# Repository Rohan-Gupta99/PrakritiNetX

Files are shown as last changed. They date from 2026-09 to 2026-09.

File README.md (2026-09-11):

# PrakritiNetX

> **An Autonomous, AI-Accelerated Environmental Early Warning & Hydro-Meteorological Intelligence Network for Flash Floods, Forest Fires, and Landslide Precursors in Mountain River Basins.**







---

## 1. Project Information

| Field | Details |
|---|---|
| **Project Title** | PrakritiNetX – AI-Accelerated Environmental Early Warning Network |
| **PS ID** | SIH2026-26178 |
| **PS Title** | AI-based environmental early warning and hydro-meteorological intelligence system for flash floods, forest fires, and landslide precursors in mountain river basins |
| **Category** | Hardware |
| **Theme** | Disaster Management |

### Team Members

| Name | Roll Number |
|---|---|
| Anishka Gupta | 2024UEC2562 |
| Rohan Gupta | 2024UEC2565 |
| Vansh Kumar | 2024UEC2519 |
| Nishant Kumar | 2024UEC2516 |
| Vivek Kumar | 2024UEC2509 |
| Animesh | 2024UEE4152 |

---

## 2. Problem Statement

Traditional environmental monitoring in India's Himalayan river basins relies on single-point **threshold-based detectors** — sensors that sound an alarm only after a river crosses a fixed water level or smoke reaches a localized probe. In steep mountain watersheds, these fixed thresholds fail physically:

- A water level routine on a wide lowland river represents a devastating flash flood on a narrow mountain gorge.
- Hardcoded threshold logic produces perpetual false alarms during seasonal snowmelt or misses sudden cloudburst pulses entirely.
- By the time an in-stream probe detects a 3-meter surge, the flood wave is already destroying infrastructure and lives downstream.
- Manual identification of forest fires and landslide precursors depends on delayed satellite imagery or chance human reporting.

There is no integrated, autonomous system that can predict flash floods, forest fires, and landslide events **before** they happen, with hours of actionable lead time, while operating off-grid in remote mountain terrain.

---

## 3. Proposed Solution

**PrakritiNetX shifts disaster management from reactive detection to predictive intelligence.** It is a distributed network of ruggedized, solar-powered edge computing nodes deployed across mountain river basins. Each node captures leading physical precursors rather than late-stage symptoms:

1. **Multi-Station Kinematic Forecasting**: Distributed edge nodes capture rate of suspended sediment turbidity change (dτ/dt), river surface texture agitation via on-device CNN vision, rainfall accumulation, and micro-seismic slope creep — all upstream precursors, not downstream consequences.
2. **Per-Site Learned Normal (30-Day μ, σ)**: Each node's baseline adapts to seasonal monsoon transitions. Anomalies are quantified via standard-deviation departures (Z ≥ 3.0σ) relative to that specific site's own historical normal — eliminating false alarms.
3. **Cross-Node Kinematic Wave Correlation**: When an upstream station flags an anomaly, the central predictive engine computes downstream arrival times (Δt = d/v) using precise field GNSS coordinates, delivering **hours of lead time** to civil defense authorities.
4. **Transparent, Auditable Escalation**: All alerting decisions follow deterministic, explainable rules matching Central Water Commission (CWC) operational standards — no black-box failures during life-safety events.

### Command Center Dashboard

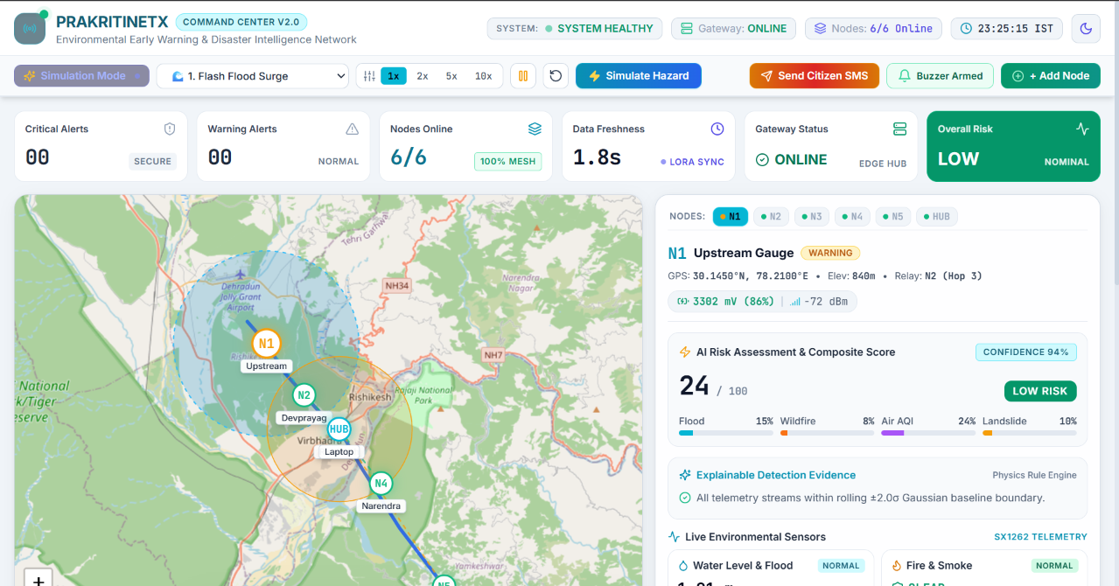
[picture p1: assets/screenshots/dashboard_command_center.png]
Command Center Dashboard


```
                    UPSTREAM SENSING STATION                               DOWNSTREAM COMMUNITY
                 [Precursor Detected at t = 0]                           [Predicted Arrival at t + Δt]
                   +------------------------+                             +------------------------+
                   | Node #1: Alaknanda #4  |                             | Node #2: Devprayag #1  |
                   | (Precise GNSS Geotag)  |                             | (Precise GNSS Geotag)  |
                   +-----------+------------+                             +-----------+------------+
                               |                                                      ^
                      Rate-of-Change (dτ/dt)                                          |
                               |                                                      |
                               v                                                      |
                   +------------------------+    Kinematic Propagation Model          |
                   | Central Predictive Hub |=========================================+
                   | (Rolling 30-day μ, σ)  |       Δt = Distance / River Velocity
                   +-----------+------------+
                               |
                   [Deterministic Rule Escalation]
                               v
                   +------------------------+
                   | NDMA SACHET / SMS / CAP| ---> District Disaster Authorities (DDMA)
                   +------------------------+      & Downstream Riverine Populations
```

---

## 4. Key Features

- **Flash Flood Prediction** — Upstream kinematic wave analysis with cross-node arrival time forecasting
- **Forest Fire Detection** — Real-time MobileNet CNN smoke/fire binary classification on K210 KPU + IR flame wake trigger
- **Landslide Precursor Monitoring** — Micro-seismic tremor filtering (ADXL355 accelerometer) + dual-axis tilt (SCA100T) for slope deformation
- **WaterNet On-Device Vision** — Tiny water-segmentation CNN (90K params, 104 KB .kmodel) for river level, coverage, turbidity, and debris measurement
- **Real-Time Command Center Dashboard** — Vite + React frontend with Python/FastAPI backend for live node monitoring, hazard simulation, and alert management
- **Per-Site Adaptive Baselines** — 30-day rolling statistical normal per node eliminates false alarms during monsoon transitions
- **Sub-GHz LoRa Mesh Network** — 433 MHz peer-to-peer mesh with ridge repeaters for zero-cellular mountain deployments
- **FieldFlash Mobile Provisioner** — Native Android (Kotlin) app for USB-OTG firmware flashing, GNSS geotagging, and node registration in the field
- **Custom PCB Design** — KiCad-designed sensor board with LoRaWAN, camera/SD, and environmental sensor subsystems
- **3D Product Design** — FreeCAD-modeled solar-powered node pole housing (STL export for manufacturing)
- **Industrial Power-Gating** — Dual power domain design (ESP32 always-on radio + K210 power-gated vision) for 10–14+ days overcast autonomy
- **NDMA/CWC Compliant Alerting** — Deterministic escalation via SACHET/CAP/SMS to District Disaster Management Authorities

---

## 5. Technology Stack

| Layer | Technologies |
|---|---|
| **Edge Compute (Lite Tier)** | ESP32-S3 (Dual Xtensa LX7 @ 240 MHz), ULP Co-Processor, TinyML |
| **Edge Compute (Vision Tier)** | Kendryte K210 (Dual RISC-V @ 400 MHz), 0.5 TOPS KPU CNN Accelerator |
| **Sensors** | Davis 7852 Rain Gauge, ADXL355 Seismic Accelerometer, SCA100T Tilt Sensor, OV5647 5MP Camera, YG1006 IR Flame Trigger |
| **Communication** | 433 MHz Sub-GHz LoRa (SX1276/RFM95), Peer-to-Peer Mesh Topology |
| **Machine Learning** | TensorFlow/Keras, TFLite, nncase v0.2 (.kmodel v4 for K210 KPU) |
| **Dashboard Frontend** | React, TypeScript, Vite, Tailwind CSS |
| **Dashboard Backend** | Python, FastAPI, SQLite, Physics Simulation Engine |
| **Mobile App** | Android Native (Kotlin), USB-OTG Serial, Room DB, WorkManager, Retrofit |
| **Backend/Cloud** | AWS API Gateway + Lambda + DynamoDB + S3 (or local Raspberry Pi gateway) |
| **PCB Design** | KiCad (Schematics, PCB Layout) |
| **3D Design** | FreeCAD (Node Pole Housing, STL Export) |
| **Power System** | 12V LiFePO4 (15–20 Ah) + MPPT Solar Controller (10–20W Monocrystalline, IP65) |
| **Compliance** | NDMA CAP, SACHET, CWC Standards |

---

## 6. Architecture

### System-Level Architecture

```
┌──────────────────────────────────────────────────────────────────────────┐
│                     FIELD DEPLOYMENT LAYER                              │
│                                                                        │
│   ┌─────────────┐   ┌─────────────┐   ┌─────────────┐                │
│   │ Lite Node #1│   │ Vision Node │   │ Lite Node #3│                │
│   │ (ESP32-S3)  │   │ (K210+ESP32)│   │ (ESP32-S3)  │                │
│   │ Hydrology & │   │ Fire & River│   │ Landslide   │                │
│   │ Landslide   │   │ Dynamics    │   │ Monitoring  │                │
│   └──────┬──────┘   └──────┬──────┘   └──────┬──────┘                │
│          │                 │                  │                        │
│          └────────── 433 MHz LoRa Mesh ───────┘                       │
│                            │                                          │
└────────────────────────────┼──────────────────────────────────────────┘
                             │
                    ┌────────▼────────┐
                    │ LoRa Gateway /  │
                    │ Ridge Repeater  │
                    └────────┬────────┘
                             │
              ┌──────────────▼──────────────┐
              │   CENTRAL INTELLIGENCE HUB  │
              │                             │
              │  • 30-day μ,σ per station   │
              │  • Kinematic wave Δt calc   │
              │  • Z-score anomaly engine   │
              │  • Cross-node correlation   │
              └──────────────┬──────────────┘
                             │
              ┌──────────────▼──────────────┐
              │     ALERT DISSEMINATION     │
              │                             │
              │  • NDMA SACHET Integration  │
              │  • CAP XML Alerts           │
              │  • SMS to DDMA / Public     │
              │  • Dashboard / Web UI       │
              └─────────────────────────────┘
```

### Hardware Node Architecture

| System Specification | Lite Tier (Hydrology & Landslide) | Vision Tier (Forest Fire & River Dynamics) |
|---|---|---|
| **Primary Compute** | ESP32-S3 (Dual Xtensa LX7 @ 240 MHz) | Kendryte K210 (Dual 64-bit RISC-V @ 400 MHz) |
| **Co-Processor** | Ultra-Low-Power (ULP) Core | ESP32 (MSM261S4030H0 module for Comms/Sleep) |
| **AI Acceleration** | Espressif Vector Instructions (TinyML) | 0.5 TOPS KPU (Dedicated CNN Hardware Accelerator) |
| **Sensor Subsystem** | Rain gauge, ADXL355 seismic accelerometer, dual-axis tilt, soil moisture | OV5647 5MP camera + telephoto M12 lens + YG1006 IR flame wake trigger |
| **Edge Workload** | Micro-tremor filtering, slope deformation, surface runoff | Real-time MobileNet CNN smoke/fire classification & optical water texture variance |
| **Radio Link** | 433 MHz Sub-GHz LoRa (SX1276/RFM95) | 433 MHz Sub-GHz LoRa via ESP32 |
| **Autonomy** | 14+ consecutive overcast days | 10+ consecutive overcast days |

### FieldFlash Mobile Provisioning Workflow

```
┌─────────────────────────┐     ┌─────────────────────────┐     ┌─────────────────────────┐
│   1. REPOSITORY CACHE   │ --> │   2. USB HOST BRIDGE    │ --> │    3. FLASH ENGINES     │
│ Cloud Manifest / SAF    │     │ CP2102, CH340, CDC-ACM  │     │ ESP32 ROM & K210 ISP    │
│ Cryptographic Signatures│     │ Hardware Auto-Reset     │     │ Adaptive Baud Fallback  │
└─────────────────────────┘     └─────────────────────────┘     └────────────┬────────────┘
                                                                             │
┌─────────────────────────┐     ┌─────────────────────────┐                  │
│   5. GEOTAG & REGISTER  │ <-- │   4. BOOT DIAGNOSTICS   │ <────────────────┘
│ Multi-Constellation GNSS│     │ Serial Telemetry Query  │ (Strict Pass / Fail
│ Local Room DB Auto-Sync │     │ Version & CRC Matching  │  Zero Bricked Devices)
└─────────────────────────┘     └─────────────────────────┘
```

### Technical Approach

The diagram below illustrates the complete end-to-end technical architecture — from the edge AI sensor nodes (Maixduino K210 + ESP32) through the LoRa mesh network, Raspberry Pi gateway hub, and cloud/local data pipeline, all the way to SMS/call civil defense alerting and mobile firmware provisioning.

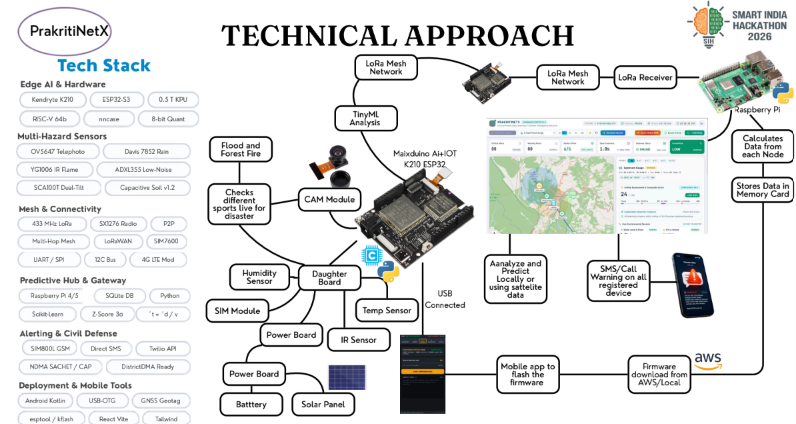
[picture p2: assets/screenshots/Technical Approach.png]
Technical Approach


---

## 7. Repository Structure

```
PrakritiNetX/
├── README.md                                    # Master project documentation
├── SUBMISSION_GUIDE.md                          # SIH 2026 submission checklist
├── LICENSE                                      # MIT Open Source License
├── requirements.txt                             # Root-level dependencies
├── .gitignore
│
├── Docs/
│   ├── Environmental Intelligence Network       # Complete technical reference (PDF)
│   │   — Complete Technical Reference.pdf
│   ├── SIH26178_PrakritiNetX_Disaster_          # SIH Presentation (PDF)
│   │   Management.pdf
│   └── architecture.md                          # Detailed system architecture document
│
├── Hardware/
│   ├── AI BOARD MAIN HOUSE/                     # Main board schematics & reference docs
│   │   ├── Advance Project 2.0.pdf
│   │   ├── Maixduino_2832(Schematic)_v1.5.pdf
│   │   └── maixduino_pins.png
│   ├── Sensor_board/                            # Custom PCB design (KiCad)
│   │   ├── Sensor_board.kicad_sch               # Main sensor board schematic
│   │   ├── Lorawan.kicad_sch                    # LoRaWAN sub-schematic
│   │   ├── camere_sd.kicad_sch                  # Camera & SD card sub-schematic
│   │   └── temp_humidity.kicad_sch              # Environmental sensor sub-schematic
│   ├── PRODUCT_DESIGN/
│   │   └── 3D_MODEL_NODE_POLE/                  # FreeCAD 3D model + STL export
│   └── Lib/                                     # KiCad component symbol library
│
├── Software/
│   ├── ML_Model/                                # WaterNet — On-device river vision CNN
│   │   ├── src/
│   │   │   ├── models/waternet.py               # KPU-legal CNN architecture (90K params)
│   │   │   ├── data/augment.py                  # Augmentation + synthetic water rise
│   │   │   ├── data/dataset.py                  # Auto-discovering image/mask loader
│   │   │   ├── train.py                         # Training (Dice + BCE loss, IoU metric)
│   │   │   └── export_kmodel.py                 # Keras → TFLite → ncc → .kmodel pipeline
│   │   ├── tools/                               # nncase v0.2 compiler & utilities
│   │   ├── firmware_ref/maixpy_node.py          # On-board K210 firmware
│   │   ├── datasets/                            # Training data directory
│   │   └── requirements.txt
│   │
│   ├── Main_Dashboard/                          # Real-Time Command Center Dashboard
│   │   ├── frontend/                            # React + TypeScript + Vite + Tailwind CSS
│   │   │   ├── src/                             # Dashboard UI components & pages
│   │   │   ├── package.json
│   │   │   └── vite.config.ts
│   │   └── backend/                             # Python FastAPI + SQLite
│   │       ├── main.py                          # API server & WebSocket endpoints
│   │       ├── physics_engine.py                # Kinematic wave & hazard simulation
│   │       ├── simulator.py                     # Multi-hazard scenario simulator
│   │       ├── database.py                      # SQLite data layer
│   │       ├── models.py                        # Pydantic data models
│   │       ├── packet_codec.py                  # LoRa binary packet encoder/decoder
│   │       └── requirements.txt
│   │
│   └── Mobile Firmware Flasher Application/     # FieldFlash — Android Provisioner App
│       ├── app/
│       │   └── src/main/java/org/prakritinetx/fieldflash/
│       │       ├── core/                        # State wrappers, constants, result models
│       │       ├── data/                        # Room SQLite DB, Retrofit REST, WorkManager
│       │       ├── engine/                      # Native ESP32 ROM & K210 ISP flash engines
│       │       ├── location/                    # GNSS location provider & board NVS writer
│       │       └── ui/                          # MVVM ViewModel, Wizard Fragments, Terminal
│       ├── mock_backend/                        # Local base-station gateway & integration tests
│       ├── preview_ui.html                      # Full-feature PC browser UI simulator
│       ├── build.gradle.kts
│       └── README.md                            # Detailed FieldFlash documentation
│
├── submission/
│   ├── PRESENTATION.md                          # Final SIH presentation (Google Drive link)
│   └── DEMO.md                                  # Demo video (Google Drive link)
│
└── assets/
    └── screenshots/                             # Project screenshots & prototype photos
        ├── Technical Approach.png               # End-to-end technical architecture diagram
        ├── dashboard_command_center.png
        ├── hardware_block_diagram.png.jpeg
        ├── hardware_pinout.png
        ├── power_architecture.png.jpeg
        └── mobile_app_pngs/                     # FieldFlash Android app screenshots
```

---

## 8. Final Presentation

📎 [View Presentation on Google Drive](https://drive.google.com/drive/folders/1Dz8FVQ1AMcFOIODErVW3VQj4AWxJVNVZ?usp=sharing)

See [submission/PRESENTATION.md](submission/PRESENTATION.md) for details.

---

## 9. Demo Video

🎬 [Watch Demo Video on Google Drive](https://drive.google.com/drive/folders/1vZj6SV4yedn8AnQawvWaI9Jvdcg6W1Xi?usp=sharing)

See [submission/DEMO.md](submission/DEMO.md) for details.

---

## 10. Screenshots / Prototype Photos

All project screenshots, hardware prototype photos, and UI captures are available in [assets/screenshots/](assets/screenshots/).

---

## 11. Installation

### Clone the Repository

```bash
git clone https://github.com/Rohan-Gupta99/PrakritiNetX.git
cd PrakritiNetX
```

### FieldFlash Mobile App (Android)

```bash
cd "Software/Mobile Firmware Flasher Application"

# Build debug APK:
./gradlew assembleDebug
```

Output: `app/build/outputs/apk/debug/app-debug.apk`

### WaterNet ML Model (Python 3.11)

```bash
cd Software/ML_Model

# Create virtual environment (using uv or venv):
uv venv .venv --python 3.11
.venv/Scripts/activate

# Install dependencies:
pip install -r requirements.txt

# Train the model (after downloading RIWA dataset to datasets/raw/):
python src/train.py --data datasets/raw --epochs 60

# Export to K210 .kmodel:
python src/export_kmodel.py --weights runs/waternet_best.h5 --calib <calibration-frames>
```

### Interactive UI Simulator (No Phone Required)

```bash
# Open directly in Chrome, Edge, or Firefox:
start "Software/Mobile Firmware Flasher Application/preview_ui.html"
```

### Main Dashboard

```bash
# Backend:
cd Software/Main_Dashboard/backend
pip install -r requirements.txt
python main.py

# Frontend (in a new terminal):
cd Software/Main_Dashboard/frontend
npm install
npm run dev
```

### Local Base-Station REST Gateway

```bash
cd "Software/Mobile Firmware Flasher Application/mock_backend"

# Run integration tests:
python test_backend_flow.py

# Start local gateway server on port 8080:
python mock_server.py
```

---

## 12. Run

### Quick Start — Command Center Dashboard

```bash
# Start backend (API + WebSocket + Simulator):
cd Software/Main_Dashboard/backend
python main.py

# Start frontend (in a new terminal):
cd Software/Main_Dashboard/frontend
npm run dev
```

### Quick Start — FieldFlash UI Preview

```bash
# No setup needed — open in any modern browser:
start "Software/Mobile Firmware Flasher Application/preview_ui.html"
```

### Deploying FieldFlash APK to Android Device

```bash
adb install app/build/outputs/apk/debug/app-debug.apk
```

---

## 13. Future Scope

- **Real River Dataset Training** — Train WaterNet on RIWA (1,100+ labelled river photos) and ATLANTIS/FloodNet datasets for production-grade accuracy across diverse river geographies
- **On-Hardware Validation** — Complete end-to-end testing of K210 MaixPy firmware on deployed Maixduino boards
- **Site Calibration System** — Two known-height reference marks per camera frame for absolute water level measurement (in meters) rather than relative readings
- **Surface Velocity Estimation** — Compute river discharge (m³/s) from camera burst sequences — the quantity CWC actually forecasts on
- **Multi-Hazard Fusion Engine** — Correlate seismic, hydrological, and fire precursors into unified multi-hazard risk scores per sub-basin
- **NavIC L5 Integration** — Leverage Indian Regional Navigation Satellite System for enhanced GNSS accuracy in mountainous terrain
- **Solar Irradiance Forecasting** — Predict node energy budgets using weather APIs to preemptively adjust sampling rates before extended overcast periods
- **Community Alert Mobile App** — Public-facing Android/iOS app for downstream communities to receive real-time evacuation alerts with estimated arrival times

---

## 14. Compliance & License

PrakritiNetX is developed as an open disaster risk reduction platform under the **MIT License**.

Architected in alignment with guidelines from the **National Disaster Management Authority (NDMA)** and the **Central Water Commission (CWC)**, Government of India.

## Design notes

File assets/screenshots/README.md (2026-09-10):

# Screenshots & Prototype Photos

This folder contains important screenshots, hardware prototype photos, and visual documentation for the PrakritiNetX project.

---

## Naming Convention

Use clear, descriptive filenames:

| Type | Example Filename |
|---|---|
| Hardware prototype | `hardware_lite_node_assembled.jpg` |
| PCB layout | `pcb_vision_tier_top.png` |
| Field deployment | `field_deployment_alaknanda.jpg` |
| Mobile app screen | `fieldflash_wizard_step1.png` |
| Dashboard UI | `dashboard_realtime_alerts.png` |
| ML model output | `waternet_segmentation_output.png` |
| Architecture diagram | `system_architecture_overview.png` |

---

## Hardware Reference

Detailed hardware schematics and pin mappings are available in [`Hardware/AI BOARD MAIN HOUSE/`](../../Hardware/AI%20BOARD%20MAIN%20HOUSE/).

## Software UI Preview

The complete FieldFlash mobile provisioning UI can be previewed in any browser using [`Software/Mobile Firmware Flasher Application/preview_ui.html`](../../Software/Mobile%20Firmware%20Flasher%20Application/preview_ui.html).

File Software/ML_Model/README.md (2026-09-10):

# WaterNet — on-node river vision for PrakritiNetX

A tiny water-segmentation CNN that runs on the **Kendryte K210** KPU and turns a
camera frame into physical measurements of the river.

> **It does not decide "flood / no flood".** It finds the water. Level,
> coverage, turbidity, turbulence and debris are then plain arithmetic on that
> water map, and the flood decision comes from how those numbers *change over
> time* — compared against this river's own learned normal, and correlated
> across nodes at the hub.
>
> This is deliberate. A single frame cannot show that a flood is coming, and a
> "flood/no-flood" image classifier learns the appearance of its training sites
> and collapses on a new camera angle. Measuring instead of classifying also
> means **we never need a photograph of a real flood** — which is fortunate,
> because we will not capture one.

---

## Status

| Stage | State |
|---|---|
| KPU-legal architecture | done — 90,401 params |
| Keras → TFLite → `.kmodel` toolchain | **working end to end** |
| Augmentation, incl. synthetic water-rise | done |
| Training pipeline | working (verified on synthetic data) |
| Trained on real river photos | **blocked — needs RIWA, see below** |
| On-board MaixPy firmware | written, **not yet run on hardware** |

Current build output:

```
build/waternet.kmodel      104 KB
  INPUT   1 x 3 x 128 x 128   uint8, straight from the camera
  OUTPUT  1 x 1 x 32  x 32    water confidence, 0..1
  Working memory   1.75 MB    (K210 has ~6 MB usable — this is the ceiling
                               on how much bigger the model can get)
```

---

## The one thing needed to finish

Download **RIWA** (River Water Segmentation Dataset, ~1,100 labelled river
photos) and unzip it anywhere under `datasets/raw/`:

<https://www.kaggle.com/datasets/franzwagner/river-water-segmentation-dataset>

The loader auto-discovers any layout with an `images/` folder beside a
`masks/` or `labels/` folder, so no rearranging is needed. Then:

```bash
.venv/Scripts/python.exe src/train.py --data datasets/raw --epochs 60
.venv/Scripts/python.exe src/export_kmodel.py --weights runs/waternet_best.h5 --calib <real-frames>
```

Useful additions if you have time: **ATLANTIS** (water bodies, ~5k images) and
**FloodNet** (flooded scenes — teaches what muddy, debris-laden water looks
like). More variety across different rivers beats more photos of one river.

---

## Why the architecture looks like this

The KPU is fixed-function silicon, not a general accelerator. It accepts only:

- Conv2D with **1×1 or 3×3** kernels — no 5×5, no 7×7, no dilation
- DepthwiseConv2D **3×3** only
- Pool 2×2/s2 or 4×4/s4 — `GlobalAveragePooling` is **not** a KPU op
- `Add`, `Concat`(channels), BatchNorm, ReLU/ReLU6
- ~2 MB for the largest activation

Two deliberate safety choices:

1. **Downsampling uses MaxPool, not stride-2 depthwise convolution.** Stride-2
   depthwise is a known K210 weak spot.
2. **Single output tensor.** Multi-output models are less reliable through the
   older `nncase`. No second head is needed anyway — lens obstruction is
   detected from image sharpness, and turbidity/debris come from the mask.

---

## Two bugs already caught, worth knowing about

**1. Double-scaling the input.** `ncc` normalises its calibration images to
0–1 itself. An extra `Rescaling(1/255)` layer inside the model divides by 255 a
second time, so the deployed model sees near-black pixels. There must be no
rescaling layer in the graph.

**2. BatchNorm running statistics — this one is nasty.** Keras defaults to
`momentum=0.99`, which needs thousands of steps to converge. On a short run the
estimates stay near their starting values and, stacked 16 layers deep, the
error compounds until every output collapses to ~0.5.

It presents as *"the model doesn't work"* while the model is actually fine:

```
inference mode (moving stats):  range 0.519..0.562   IoU 0.405   broken
training  mode (batch stats) :  range 0.001..1.000   IoU 0.862   fine
```

This matters more here than in ordinary training, because **BatchNorm is folded
into the convolution weights during `.kmodel` export.** Bad statistics get baked
permanently into the file you flash — it loads fine and predicts nothing.

Fixed by setting `BN_MOMENTUM = 0.9`. `export_kmodel.py` now also refuses to
export quietly: it checks the output spread and warns if the model is producing
near-constant values.

---

## Manufacturing floods we never photographed

`raise_water()` in `src/data/augment.py` takes a calm-river photo, pushes the
waterline up the bank, fills the newly-flooded strip with real water texture
mirrored from below the old line, and returns the exactly-known new mask.

Measured: **40% → 68% water coverage from a single photograph.**

That produces correctly-labelled training images at water levels that have
never occurred — precisely the regime we must detect. Stepping it upward frame
by frame also turns one real photo into a convincing rising-river sequence for
the demo.

---

## Layout

```
src/models/waternet.py      the model — every KPU restriction encoded here
src/data/augment.py         augmentation + synthetic water rise
src/data/dataset.py         auto-discovering image/mask loader
src/train.py                training (Dice + BCE loss, IoU metric)
src/export_kmodel.py        Keras -> TFLite -> ncc -> .kmodel, with a sanity check
tools/ncc/ncc.exe           nncase v0.2 compiler (kmodel v4, the format MaixPy loads)
tools/make_synthetic_dataset.py   pipeline smoke-test data, not real training data
firmware_ref/maixpy_node.py on-board firmware: burst capture, inference, features, packet
```

**Note on `nncase`:** the `nncase` package on PyPI (v2.x) targets the **K230**,
not the K210. The K210 needs the older `ncc` v0.2, vendored in `tools/ncc/`,
which produces kmodel **v4** — the format MaixPy actually loads.

---

## Environment

TensorFlow does not support Python 3.14, so training runs in a separate
Python 3.11 environment at `.venv/` (created with `uv`). The `ncc` compiler is
a standalone binary and needs no Python at all.

---

## Not yet done

- Trained on real river imagery (needs RIWA)
- `maixpy_node.py` run on actual hardware — points needing on-device checks are
  marked `# VERIFY`
- Site calibration: two known-height marks in frame, measured with a tape at
  installation. Without it, levels are relative rather than in metres.
- Surface velocity from the burst (gives discharge in m³/s — the quantity the
  Central Water Commission actually forecasts on)

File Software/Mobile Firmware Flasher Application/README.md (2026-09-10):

# FieldFlash: Native Android Firmware Flasher & Geotagging Provisioner

**FieldFlash** is an enterprise-grade native Android (Kotlin) engineering application developed for field technicians deploying **PrakritiNetX** remote IoT environmental sensor nodes across mountain slopes, river gauge stations, and forest ridges with zero reliable internet access.

FieldFlash provides robust, reliable firmware flashing over USB-OTG, hardware boot and diagnostic verification, offline firmware caching, and post-installation GNSS geotagging with guaranteed-delivery offline queuing.

---

## 1. Operational Hardware Context & Supported Silicon

In accordance with the **PrakritiNetX Technical Specifications**:
- **ESP32-S3 ("Lite" Tier)**: Used for hydrology and flood monitoring (rain gauge, optical turbidity, water level) and seismic/landslide precursor sensing (ADXL355 low-noise accelerometer, dual-axis tilt, capacitive soil moisture).
- **Kendryte K210 ("Vision" Tier)**: Dual-core 64-bit RISC-V SoC with a hardware KPU running quantized MobileNet CNNs for smoke/fire detection and scene feature extraction.
- **Combined Architecture (e.g. Sipeed Maixduino)**: K210 for KPU edge vision paired with ESP32 for 433 MHz LoRa mesh transmission and power management.
- **Supported USB Bridges**: Silicon Labs CP2102/CP2104, WCH CH340/CH341, FTDI FT232R/FT2232, and native ESP32 USB CDC/JTAG.

---

## 2. Architecture & Engine Design

```
FieldFlash Architecture
├── UI Layer (MVVM + Jetpack Navigation)
│   ├── Step 1: Repository (Production Manifest / Offline Cache / SAF Storage)
│   ├── Step 2: USB Host Bridge & Hardware Probing (CP2102, CH340, FTDI, CDC-ACM)
│   ├── Step 3: Native Flashing Engine (Live progress, adaptive baud, terminal log)
│   ├── Step 4: Diagnostics & Safety (Run mode reset, telemetry query, version check)
│   ├── Step 5: GNSS Geotag & Registration (Multi-constellation lock, NVS writeback)
│   └── Gateway Settings & Queue (Pending sync list, base-station URL configuration)
│
├── Flashing Engines
│   ├── ESP32 Native Serial Engine (Espressif ROM protocol, SLIP framing, MD5 verify)
│   └── K210 ISP Flashing Engine (Kendryte ISP protocol, .kfpkg zip unpacker, standalone .bin)
│
├── Serial Layer (usb-serial-for-android)
│   ├── UsbSerialManager (USB Host API, DTR/RTS hardware auto-reset)
│   └── SlipFraming (RFC 1055 encoder/decoder)
│
├── Data & Offline Synchronization
│   ├── Room Database (QueuedLocationEntity & CachedFirmwareEntity)
│   ├── WorkManager (LocationSyncWorker with NetworkType.CONNECTED constraint)
│   └── Retrofit / OkHttp REST Client (Decoupled generic endpoints)
```

### Native Kotlin Serial Protocol (Zero Binary Sub-Processes)
On Android 10+ (`targetSdkVersion >= 29`):
1. **SELinux `W^X` Compliance**: The Android OS strictly blocks executing sub-process ELF binaries from app-private storage (`/data/data/...`), throwing `java.io.IOException: error=13, Permission denied`.
2. **Direct USB Host Management**: Non-root Android applications cannot access `/dev/ttyUSB*` directly. All hardware communications must flow through Android's `UsbManager` and `UsbDeviceConnection`.
3. **FieldFlash Implementation**: Directly communicates with the Android USB Host API via `usb-serial-for-android`. Implements the Espressif Bootloader Protocol natively in Kotlin (DTR/RTS auto-reset, SLIP framing, ROM sync `0x08`, adaptive baud rate negotiation up to 921,600 bps, flash sector writes `0x03`, and hardware ROM MD5 verification `0x13`).

---

## 3. Flashing Engines

### ESP32-S3 Flashing Engine
Flashes three files at their required fixed memory offsets:
1. `bootloader.bin` at `0x0000` (or `0x1000` for ESP32 legacy)
2. `partition-table.bin` at `0x8000`
3. Application firmware `.bin` at `0x10000`

- **Hardware Auto-Reset**: Controlled via DTR/RTS lines:
  - RTS = HIGH (active-low EN asserted -> reset held)
  - DTR = HIGH (active-low IO0 asserted -> bootloader mode selected)
  - RTS released -> chip boots into ROM bootloader
- **Integrity Validation**: Issues `ESP_SPI_FLASH_MD5` to compute and match MD5 digests against the original binary before reporting block completion.

### Kendryte K210 ISP Flashing Engine
Completely isolated module (`org.prakritinetx.fieldflash.engine.k210`):
- **Package Modes**:
  1. Full `.kfpkg` bundle: Unzips archive, reads `flash-list.json`, extracts binaries (bootloader, runtime, `.kmodel` neural network weights), and writes each entry to its specified address.
  2. Standalone `.bin` application update: Flashes application binary directly to specified offset (e.g. `0x000000` or custom) without overwriting bootloader or neural network models.
- **Protocol**: Kendryte ISP greeting (`0xC1`), reads 64-bit factory unique device ID, switches UART baud rate up to 1,500,000 bps, initializes flash (`0xC4`), and writes 4KB chunks (`0xC5`) with ISP ACK handshakes.

---

## 4. Post-Flash Diagnostics & Verification Protocol

Because PrakritiNetX nodes are deployed in remote, physically inaccessible mountain terrain, **devices must never be left in an uncertain or bricked state**.

1. **Hardware Reboot**: Releases DTR/RTS and resets MCU into normal runtime application mode.
2. **Diagnostics Query**: Switches baud to standard runtime speed (115,200 bps) and transmits verification queries (`CMD:GET_VERSION\r\n`, `SYS:DIAGNOSTICS\r\n`).
3. **Live Telemetry Parsing**: Extracts runtime battery voltage ($V_{bat}$), state of charge (%), solar array input voltage, internal temperature, LoRa radio frequency, and sensor bus status.
4. **Safety Enforced**: The app **only** displays a success state and enables the geotagging step if verification explicitly passes. If the board fails to boot or returns a version mismatch, an unambiguous failure banner is shown.

---

## 5. Location Geotagging & Offline-First Sync

- **Separation of Concerns**: Geotagging is explicitly decoupled from flashing. Technicians often flash nodes in a base camp workshop; geotagging is triggered **only** once the node is physically mounted at its riverbank or mountain site.
- **Multi-Constellation GNSS**: Captured via Google Play Services `FusedLocationProviderClient` with `PRIORITY_HIGH_ACCURACY` (recording Latitude, Longitude, Altitude, Accuracy in meters, Satellites used, Constellation type, and HDOP).
- **Node ID Association**: Automatically tagged with the unique hardware ID read during the flash/handshake step (ESP32 MAC or K210 64-bit Chip ID).
- **On-Board NVS Redundancy**: Writes captured coordinates back to the board over USB-serial (`CONFIG:LOC:<lat>,<lon>,<alt>,<acc>,<time>\r\n`) so the node can store its own position in flash/EEPROM.
- **Offline Queuing**: When offline at the deployment site, records are stored in a local Room database (`QueuedLocationEntity`).
- **Guaranteed Auto-Sync**: Background `LocationSyncWorker` is enqueued with `NetworkType.CONNECTED` constraint via `WorkManager`. As soon as the technician returns to cellular/Wi-Fi coverage, pending records automatically sync to the backend cloud.

---

## 6. Decoupled REST API Specification

The app communicates with a backend REST service. The base URL is configurable in the app's Settings screen (`http://<server-ip>:8080/` or AWS API Gateway endpoint).

### 1. Firmware Manifest
- **Endpoint**: `GET /firmware/manifest`
- **Response**:
```json
{
  "network": "PrakritiNetX",
  "manifest_version": "2.4.0",
  "release_channel": "production-stable",
  "packages": [
    {
      "id": "prakriti-water-esp32-v2.4.0",
      "node_type": "water-esp32",
      "display_name": "Hydrology & Flood Early Warning Node (ESP32-S3)",
      "version": "v2.4.0",
      "chip_type": "esp32",
      "description": "Camera turbidity analysis, optical water level, and tipping-bucket rain gauge telemetry.",
      "files": [
        { "name": "bootloader.bin", "offset": "0x0000", "download_url": "firmware/download/bootloader.bin" },
        { "name": "partition-table.bin", "offset": "0x8000", "download_url": "firmware/download/partition-table.bin" },
        { "name": "prakriti_water_v2.4.0.bin", "offset": "0x10000", "download_url": "firmware/download/prakriti_water_v1.4.0.bin" }
      ]
    }
  ]
}
```

### 2. File Download
- **Endpoint**: `GET /firmware/download/{filename}`
- **Response**: Binary octet-stream of the requested firmware payload.

### 3. Geotag Registration
- **Endpoint**: `POST /nodes/{node_id}/location`
- **Payload**:
```json
{
  "node_id": "30:AE:A4:07:0D:64",
  "latitude": 30.316496,
  "longitude": 78.032188,
  "altitude": 1420.5,
  "accuracy": 2.4,
  "satellites_used": 14,
  "gnss_constellation": "GPS+NavIC+GLONASS",
  "hdop": 0.85,
  "timestamp": 1789035600000,
  "firmware_version": "v2.4.0",
  "chip_type": "esp32",
  "catchment_basin": "Alaknanda Upper Catchment",
  "mounting_height_meters": 24.5,
  "written_to_board": true,
  "battery_voltage_mv": 12450,
  "technician_notes": "Alaknanda River Catchment - Bridge Pillar Node #3"
}
```
- **Response**:
```json
{
  "status": "SUCCESS",
  "message": "Deployment location confirmed and registered for node 30:AE:A4:07:0D:64",
  "id": "30:AE:A4:07:0D:64"
}
```

---

## 7. Testing & Verification

### 1. Interactive UI Simulator
Test the complete mobile flow directly on any PC browser:
```bash
# Open in your browser:
preview_ui.html
```

### 2. Local Base-Station REST Gateway Server
A standalone Python REST gateway is included in `mock_backend/`:
```bash
cd mock_backend

# Run automated integration test
python test_backend_flow.py

# Start the interactive local gateway server
python mock_server.py
```

### 3. Building FieldFlash for Android
```bash
# Build Debug APK
./gradlew assembleDebug
```
Output APK: `app/build/outputs/apk/debug/app-debug.apk`

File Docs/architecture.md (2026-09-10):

# PrakritiNetX — System Architecture

## Overview

PrakritiNetX is a distributed environmental early warning network that shifts disaster management from reactive detection to predictive intelligence. The system comprises three main layers:

1. **Field Deployment Layer** — Ruggedized, solar-powered edge computing nodes
2. **Central Intelligence Hub** — Kinematic prediction engine with adaptive baselines
3. **Alert Dissemination Layer** — NDMA/CWC compliant multi-channel alerting

---

## System-Level Architecture

```
┌──────────────────────────────────────────────────────────────────────────┐
│                     FIELD DEPLOYMENT LAYER                              │
│                                                                        │
│   ┌─────────────┐   ┌─────────────┐   ┌─────────────┐                │
│   │ Lite Node #1│   │ Vision Node │   │ Lite Node #3│                │
│   │ (ESP32-S3)  │   │ (K210+ESP32)│   │ (ESP32-S3)  │                │
│   │ Hydrology & │   │ Fire & River│   │ Landslide   │                │
│   │ Landslide   │   │ Dynamics    │   │ Monitoring  │                │
│   └──────┬──────┘   └──────┬──────┘   └──────┬──────┘                │
│          │                 │                  │                        │
│          └────────── 433 MHz LoRa Mesh ───────┘                       │
│                            │                                          │
└────────────────────────────┼──────────────────────────────────────────┘
                             │
                    ┌────────▼────────┐
                    │ LoRa Gateway /  │
                    │ Ridge Repeater  │
                    └────────┬────────┘
                             │
              ┌──────────────▼──────────────┐
              │   CENTRAL INTELLIGENCE HUB  │
              │                             │
              │  • 30-day μ,σ per station   │
              │  • Kinematic wave Δt calc   │
              │  • Z-score anomaly engine   │
              │  • Cross-node correlation   │
              └──────────────┬──────────────┘
                             │
              ┌──────────────▼──────────────┐
              │     ALERT DISSEMINATION     │
              │                             │
              │  • NDMA SACHET Integration  │
              │  • CAP XML Alerts           │
              │  • SMS to DDMA / Public     │
              │  • Dashboard / Web UI       │
              └─────────────────────────────┘
```

---

## Dual-Tier Edge Node Architecture

### Lite Tier (Hydrology & Landslide Monitoring)

```
┌─────────────────────────────────────────────┐
│            ESP32-S3 (Lite Node)             │
│         Dual Xtensa LX7 @ 240 MHz          │
├─────────────────────────────────────────────┤
│                                             │
│  ┌──────────┐  ┌──────────┐  ┌──────────┐ │
│  │Rain Gauge│  │ ADXL355  │  │ SCA100T  │ │
│  │Davis 7852│  │ Seismic  │  │Dual Tilt │ │
│  └────┬─────┘  └────┬─────┘  └────┬─────┘ │
│       │              │              │       │
│       └──────────────┼──────────────┘       │
│                      │                      │
│              ┌───────▼───────┐              │
│              │  TinyML Edge  │              │
│              │  Processing   │              │
│              └───────┬───────┘              │
│                      │                      │
│              ┌───────▼───────┐              │
│              │  LoRa Radio   │              │
│              │  SX1276 433MHz│              │
│              └───────────────┘              │
│                                             │
│  Power: 12V LiFePO4 + MPPT Solar           │
│  Autonomy: 14+ overcast days               │
│  Sleep Current: ~15 µA (deep sleep)        │
└─────────────────────────────────────────────┘
```

### Vision Tier (Forest Fire & River Dynamics)

```
┌─────────────────────────────────────────────────────────────────┐
│                    Vision Node (Dual-SoC)                       │
├──────────────────────────┬──────────────────────────────────────┤
│   DOMAIN A (Always On)   │   DOMAIN B (Power-Gated)            │
│                          │                                      │
│   ┌──────────────────┐   │   ┌──────────────────┐              │
│   │     ESP32        │   │   │   Kendryte K210   │              │
│   │  Comms + Sleep   │   │   │  RISC-V @ 400MHz │              │
│   └────────┬─────────┘   │   │  0.5 TOPS KPU    │              │
│            │              │   └────────┬─────────┘              │
│   ┌────────▼─────────┐   │   ┌────────▼─────────┐              │
│   │  LoRa SX1276     │   │   │  OV5647 5MP      │              │
│   │  433 MHz Radio   │   │   │  + M12 Telephoto │              │
│   └──────────────────┘   │   └──────────────────┘              │
│                          │                                      │
│   Current: 112-130 mA   │   P-MOSFET Load Switch               │
│   (Continuous mesh       │   ON: 3-5 sec every 10-15 min       │
│    relay routing)        │   OFF: Absolute 0.0 mA              │
├──────────────────────────┴──────────────────────────────────────┤
│  Power: 12V LiFePO4 + MPPT Solar | Autonomy: 10+ overcast days│
└─────────────────────────────────────────────────────────────────┘
```

---

## Communication: 433 MHz LoRa Mesh

```
Radio Band:       433 MHz ISM (License-Free, India)
Topology:         Peer-to-Peer Multi-Hop Mesh
Packet Size:      14 Bytes (Compact Binary)
Modulation:       LoRa (SX1276 / RFM95)

┌───────────┬──────────────┬──────────┬─────────────────┬────────────────┬────────────┬────────────────┬──────────┐
│ Node ID   │ Timestamp    │ Msg Type │ Primary Reading │ Rate of Change │ Battery mV │ Secondary Flag │ Checksum │
│ (1 Byte)  │ (4 Bytes)    │ (1 Byte) │ (2 Bytes)       │ (2 Bytes)      │ (2 Bytes)  │ (1 Byte)       │ (1 Byte) │
└───────────┴──────────────┴──────────┴─────────────────┴────────────────┴────────────┴────────────────┴──────────┘
```

---

## WaterNet ML Pipeline

```
Training Pipeline:
  Keras Model (90K params) → TFLite → nncase v0.2 → .kmodel v4

On-Device Inference:
  Camera Frame (128x128 RGB) → K210 KPU → Water Mask (32x32) → Feature Extraction

Features Extracted:
  • Water level (pixel coverage)
  • Turbidity (color channel analysis)
  • Surface turbulence (texture variance)
  • Debris detection (mask anomalies)
```

---

## FieldFlash Provisioning Pipeline

```
┌─────────────────────────┐     ┌─────────────────────────┐     ┌─────────────────────────┐
│   1. REPOSITORY CACHE   │ --> │   2. USB HOST BRIDGE    │ --> │    3. FLASH ENGINES     │
│ Cloud Manifest / SAF    │     │ CP2102, CH340, CDC-ACM  │     │ ESP32 ROM & K210 ISP    │
│ Cryptographic Signatures│     │ Hardware Auto-Reset     │     │ Adaptive Baud Fallback  │
└─────────────────────────┘     └─────────────────────────┘     └────────────┬────────────┘
                                                                             │
┌─────────────────────────┐     ┌─────────────────────────┐                  │
│   5. GEOTAG & REGISTER  │ <-- │   4. BOOT DIAGNOSTICS   │ <────────────────┘
│ Multi-Constellation GNSS│     │ Serial Telemetry Query  │ (Strict Pass / Fail
│ Local Room DB Auto-Sync │     │ Version & CRC Matching  │  Zero Bricked Devices)
└─────────────────────────┘     └─────────────────────────┘
```

---

## Predictive Intelligence Flow

```
1. Upstream Node Detects Precursor
   └─→ Rate-of-change (dτ/dt) exceeds Z ≥ 3.0σ from 30-day baseline

2. Alert Packet Transmitted via LoRa Mesh
   └─→ Priority escalation over routine telemetry

3. Central Hub Receives & Correlates
   └─→ Cross-node kinematic wave analysis
   └─→ Downstream arrival time: Δt = Distance / River Velocity

4. Deterministic Escalation
   └─→ NDMA SACHET notification
   └─→ CAP XML alert to DDMA
   └─→ SMS to downstream populations

5. Lead Time Delivered
   └─→ Hours of advance warning before flood wave arrival
```

---

## Technology Summary

| Component | Technology |
|---|---|
| Lite Node Compute | ESP32-S3, ULP Co-Processor |
| Vision Node Compute | Kendryte K210 KPU + ESP32 |
| Sensors | Davis 7852, ADXL355, SCA100T, OV5647, YG1006 |
| Radio | 433 MHz LoRa (SX1276/RFM95) |
| ML Framework | TensorFlow/Keras → TFLite → nncase → .kmodel |
| Mobile App | Android Native (Kotlin), USB-OTG |
| Backend | AWS (API Gateway + Lambda + DynamoDB + S3) |
| Power | 12V LiFePO4 + MPPT Solar (IP65) |
| Compliance | NDMA CAP, SACHET, CWC Standards |

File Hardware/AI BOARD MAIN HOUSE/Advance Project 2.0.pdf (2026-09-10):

I'll drop the SVG/Figma build and give you the complete deep-dive write-up instead, in chat, covering everything discussed across this whole conversation — physics, math, exact component names, logic, algorithms, and flow, end to end.

## Environmental Intelligence Network — Complete Technical Reference

PART 1: THE CORE PHILOSOPHY

### 1.1 Detector vs. Predictor — the foundational distinction

A detector is a system that reacts once a condition is already true. A water sensor that fires an alarm when the river crosses a fixed height (say, 3 meters) is a detector. Its fundamental flaw: by the time water is at 3 meters, the flood is already arriving. People downstream get minutes of warning, sometimes none.

A predictor is a system that identifies the pattern that precedes a dangerous condition, before that condition exists. This requires:

- Multiple sensing points spread across a geographic area (not one sensor)
- A memory of what "normal" looks like at each point, built from historical data
- A method to detect deviation from that normal, and to project forward: given this deviation, when will its effects reach a different point?

The entire architecture below exists to make this second thing possible, not the first.

### 1.2 Why fixed thresholds are wrong, physically

A river's baseline behavior is a function of: catchment area, seasonal rainfall, snowmelt contribution (relevant in Himalayan contexts), channel geometry, and even time of day for glacier-fed streams. There is no universal number for "dangerous." A water level or turbulence value that is completely routine on a wide monsoon-fed lowland river would represent a major event on a narrow, steep mountain torrent, and vice versa.

This means: any alerting logic that uses an absolute, hardcoded threshold value will either produce constant false alarms on naturally turbulent rivers, or fail to trigger at all on naturally calm ones that are actually in danger.

The mathematical fix is to make "normal" a learned, per-site, time-varying quantity rather than a constant. This is developed fully in Part 5.

PART 2: SENSING — WHAT EACH NODE MEASURES AND HOW

### 2.1 Why we rejected several sensing approaches, in order

Rejected: MPU6050 accelerometer for seismic/flood vibration sensing as a primary signal.
Physics reason: the MPU6050 is a MEMS accelerometer with a noise density around 400 micro-g per root-Hz (µg/√Hz), and typical resolution of about 0.06 mg per LSB at the ±2g range setting. Real-world earthquake or flood-adjacent ground vibration signals that matter — especially from moderate or distant events — often sit in the range of single-digit to tens of milli-g. That's within the same order of magnitude as the sensor's own noise floor, meaning the signal gets buried in noise. Additionally, the MPU6050 has no built-in temperature compensation, and MEMS accelerometers drift thermally — over the timescales relevant to slow-building hazards (hours), this drift alone can exceed the signal you're trying to measure. Proper seismic-grade instruments (geophones, or accelerometers like the ADXL355 with noise density near 25 µg/√Hz) are roughly an order of magnitude quieter.

Rejected: ground vibration sensing at 50-100m from a riverbank to detect flow-based vibration.
Physics reason: soil is a lossy transmission medium. Vibrational energy from turbulent water flow attenuates and disperses as it travels through ground — high-frequency components attenuate fastest. At 50-100 meters, whatever signal originated at the riverbank is heavily attenuated and buried under everyday ambient ground noise (wind loading on structures, vehicle traffic, animals, thermal expansion/contraction of the sensor's own mount). This is true even with seismic-grade equipment; the physical signal path itself is too weak at that distance for this specific technique, independent of sensor quality.

Rejected: ultrasonic distance sensors (e.g., HC-SR04-class) for water level at any meaningful mounting height.
Physics reason: cheap ultrasonic time-of-flight sensors have a practical reliable range of roughly 4-5 meters, with accuracy degrading substantially beyond 2-3 meters. Given that Himalayan flood surges can rise 5-7 floors (roughly 15-25 meters) above baseline river level, any sensor mounted high enough to physically survive such a surge is now far outside ultrasonic's usable range. Ultrasonic is also sensitive to wind, temperature, and humidity gradients in the air column between sensor and target — conditions that are actively adverse during the storm events you most need reliable readings from.

Rejected: standard industrial radar level sensors at 15-25m range in open river valleys. Reason: while industrial non-contact radar (used in tanks, silos) is often rated for 15-30+ meters, that rating assumes a controlled, contained environment. An open-air mountain river valley introduces wind, spray, surface turbulence, and highly variable target geometry (the water surface itself is chaotic during a flood) that degrades real-world performance well below the datasheet rating for a contained vessel. This is a real, unresolved gap flagged for direct consultation with domain-expert mentors (hydrology/ISRO-adjacent), since actual operational Himalayan river gauge stations (run by India's Central Water Commission) have solved this class of problem and are the correct reference to consult rather than reverse-engineering it from consumer sensor datasheets.

Adopted, with caveats: camera-based vision from a stable elevated position.
Reasoning: unlike echo-based sensing (ultrasonic, radar), optical sensing degrades much more gracefully with distance — resolvability is a function of focal length and sensor resolution, not signal attenuation through a medium. This is why the final design uses a camera mounted on stable high ground (a hillside or riverbank slope, not a pole standing in the flood's path), angled downward at roughly 30-40 degrees, giving a single frame that captures both the river below and the forest/slope above.

### 2.2 The optics problem, in detail

At a real-world distance of approximately 20-30 meters (10 floors, per your stated deployment plan), the governing constraint is resolution-on-target: how many pixels of the sensor actually correspond to the feature you need to measure.

Standard hobbyist camera modules (Sony/OmniVision sensors like the OV2640 or the base OV5647) ship with wide-angle, fixed-focus lenses intended for close-range framing (a few meters). At 30 meters through a wide lens, a target object occupies a very small angular fraction of the frame — potentially only 10-20 pixels of vertical extent for something like a reference gauge board, which is insufficient for reliable pixel-level analysis.

The fix is focal length, not sensor megapixels. The recommended approach:

- OV5647 (5MP sensor) paired with a manually adjustable or fixed telephoto M12-mount lens (a well-documented modification in the Raspberry Pi camera community, since the OV5647 is the same sensor used in early Pi Camera modules) — this trades field of view for magnification, putting more pixels on the actual target
- Alternative: repurpose CCTV/security-industry camera modules that come with integrated optical zoom and long-range IR illuminators (rated 20-30m+), since long-range night vision at this distance is a solved problem in that industry, just not in the typical ESP32-CAM hobbyist ecosystem
- Mandatory validation step: physically test resolution-on-target at the real deployment distance and angle before finalizing a part — this cannot be correctly selected from a datasheet alone

Night/low-light operation requires either an IR-capable sensor (no IR-cut filter) paired with IR illumination that can actually project 20-30 meters (most cheap IR LED arrays only reach a few meters, so this needs a purpose-built long-range IR illuminator, again borrowed from the security-camera industry).

### 2.3 What the vision model actually computes — feature extraction, not classification

A critical design decision: the on-node vision system does not output a final "flood: yes/no" judgment. It outputs a small set of continuous numeric features per captured frame:

1. Turbidity/color estimate — a numeric proxy for how muddy/sediment-laden the water appears. Physical basis: upstream erosion and surface runoff increase suspended sediment concentration before the increased water volume itself has physically arrived downstream, since sediment-laden runoff can enter the channel from slopes closer to the observation point than the main flood pulse. This makes turbidity trend the single strongest leading indicator among the three extracted features.
2. Turbulence score — a rough measure of surface agitation/texture, computed from frame-to-frame variance or optical flow magnitude in the water region. Physical basis: increased flow rate/volume typically increases surface turbulence. Caveat: this signal is also affected by wind and normal daily flow variation unrelated to flooding, so it is a noisier, more ambiguous signal on its own and only becomes meaningful when compared against that specific site's own historical turbulence baseline.
3. Water coverage percentage — the fraction of the frame's expected river channel area that is currently covered by water, a coarse proxy for absolute water level. This is fundamentally a confirmatory/detection signal, not predictive — by the time coverage percentage rises, water has already arrived at that visual position.

None of these three features alone constitutes prediction. Prediction emerges from combining rate of change over time in these features with cross-node correlation (developed in Part 5) — this is the architectural point where "the intelligence lives in the network, not in any single node."

### 2.4 Fire/forest sensing

Primary approach: camera-based binary classification (fire/smoke present vs. absent), using a small convolutional neural network. The camera may be shared with the water-monitoring camera if a single wide frame covers both river and forest/slope (an open design question flagged for team decision), since fire/smoke visual detection is a well-precedented technique in real forest-fire camera networks — wide-area smoke/haze detection from elevated fixed cameras is an established real-world method.

Explicitly rejected as unreliable on its own: naive color-based fire detection ("classify orange pixels as fire") — this produces high false-positive rates from sunsets, orange-colored objects/tarps, and warning lights, which is precisely why a properly trained CNN with deliberately collected negative/false-positive training examples is required rather than a simple color heuristic.

Supplementary sensor: an IR flame sensor (specific part: YG1006 flame sensor module) — reframed not as a competing detection method, but as a low-power, always-on wake trigger. Since flame sensors draw negligible current and can run continuously, they can serve as a cheap pre-filter that wakes the power-hungry camera+AI pipeline only when there's a preliminary indication worth a closer look, saving battery.

### 2.5 Seismic/landslide/avalanche sensing — explicitly non-visual

This is the one hazard category where camera vision was deliberately excluded as the primary method, for a specific physical reason: avalanches are frequently obscured by the whiteout/snow conditions they themselves create, making optical sensing structurally unreliable exactly when it matters most. Landslide precursors (slow ground creep, crack widening) are also not inherently visual signals in the way flame or water-level change are.

Real early-warning systems for this hazard category (referenced from institutions like the Geological Survey of India and IIT Roorkee's landslide monitoring work) use:

- Geophones or seismic-grade accelerometers (specific upgrade path identified: ADXL355 low-noise accelerometer, versus the MPU6050 starting point) to detect ground micro-tremors preceding slope failure
- Tilt sensors / inclinometers (specific part: SCA100T-D02 or generic dual-axis tilt sensor modules) to measure slope angle change over time
- Extensometers — sensors that measure the widening of surface cracks, a direct mechanical precursor to slope failure
- Soil moisture sensors (specific part: capacitive soil moisture sensor v1.2) — since soil saturation is a primary landslide trigger mechanism, tracking moisture trend is itself a predictive signal, analogous to turbidity for flood

This entire hazard category was flagged explicitly as the least-researched in the project, with a direct recommendation to consult ISRO-adjacent or geological-survey-experienced mentors for validated reference architectures rather than inventing an approach from first principles.

PART 3: HARDWARE — EXACT COMPONENTS AND WHY

### 3.1 The chip-selection logic, stated as a general principle

The recurring analytical error to avoid: assuming more powerful compute improves accuracy on a task that isn't compute-bound. Accuracy in water-level sensing, for example, is bounded by optics, calibration, and physical sensor placement — not by neural network capacity. Adding a more powerful AI chip to a task like this adds cost, power draw, and toolchain complexity for zero accuracy benefit. Compute should be matched to the specific computational demand of each task, not applied uniformly at the highest available tier "to be safe."

### 3.2 Microcontroller/SoC options evaluated

ESP32-S3 — the workhorse choice for lightweight sensing nodes (non-vision-heavy tasks, and orchestration/connectivity duties even on vision nodes). Rationale: mature ecosystem (Espressif's official ESP-IDF framework, and Arduino framework support), built-in AI vector instructions sufficient for genuinely simple TinyML tasks (wake-word style classification, coarse image classification with heavily quantized models), and well-documented low-power deep sleep modes at the microamp level. Camera support available via modules like the XIAO ESP32-S3 Sense.

K210 (Kendryte K210) — a dual-core RISC-V 64-bit SoC (28nm process, IMAFDC instruction set, 8MB on-chip high-speed SRAM, 400MHz clock, overclockable to 800MHz) with a dedicated KPU (Kendryte Processing Unit) — a hardware neural network accelerator, not a general-purpose CPU running ML in software. The KPU is rated at 0.25 TOPS at 0.3W at 400MHz, or 0.5 TOPS at 800MHz overclocked, cited as sufficient for object recognition at 60fps at VGA resolution. This is the correct choice specifically for nodes running real CNN inference (fire/smoke classification, or future water-scene feature extraction via vision), because it performs this class of computation in dedicated silicon rather than software emulation on a general CPU — the same task on a Raspberry Pi Zero 2 W's CPU alone was benchmarked by community users at roughly 6 seconds per inference using standard TFLite object detection scripts, versus the K210's real-time capability.

K230 (Kendryte's successor to K210) — offers roughly 6 TOPS equivalent AI performance, cited as approximately 13.7 times the K210's AI throughput and 8.5 times its general CPU compute. Comes in modules with integrated support for 30+ pre-built AI vision features (object, face, gesture, text, digit recognition) and simplified training tooling. Trade-off: newer, less field-proven, smaller community/toolchain maturity than K210.

Sipeed Maixduino — a specific combined board (K210 + ESP32 module + integrated camera connector, in an Arduino Uno form factor) evaluated as a practical way to get both KPU-based inference and WiFi/Bluetooth connectivity on one PCB without designing a custom two-chip board from scratch. Specification details confirmed from its datasheet: power input via USB-C DC-DC step-down circuit supporting 6-12V input, providing 5V at 1.2A output; ESP32 module (specifically MSM261S4030H0-class) supports 2.4GHz 802.11 b/g/n WiFi up to 150Mbps and Bluetooth v4.2 (BR/EDR + BLE); 24-pin 0.5mm FPC camera connector. Important limitation identified: this board's onboard wireless is WiFi/Bluetooth only — it does not include LoRa, meaning an external LoRa module (e.g., an SX1276/RFM95-based module) must still be added via the board's exposed pins to fit the project's long-range mesh communication requirement.

Raspberry Pi Zero 2 W — evaluated and set aside for on-node use specifically because it lacks any dedicated neural network accelerator; it runs inference via its general-purpose quad-core Cortex-A53 CPU in software, which was benchmarked (via community-reported testing) at roughly 6 seconds per TFLite object-detection inference — acceptable for a task that only needs periodic checking (not real-time video), but a genuine step down in efficiency versus the K210's hardware-accelerated approach, and it draws meaningfully more idle/active power than an ESP32-S3 with no compensating advantage for this specific workload. It remains the correct choice for the central hub, not individual sensing nodes, once migrated from a laptop for field deployment.

### 3.3 The two-processor relationship on a combined board (K210 + ESP32)

A specific misconception addressed directly: on a board like the Maixduino, the K210 and ESP32 are two entirely separate processors with their own separate RAM, typically connected via UART or SPI — not a shared-memory architecture where one chip's memory is accessible to the other. The ESP32 cannot "help compute" the AI inference task; it has no path to meaningfully accelerate what happens inside K210's KPU.

The correct division of responsibility:

- K210's job: run the camera capture and KPU inference — the one task it's uniquely equipped for — and stay powered down otherwise
- ESP32's job: everything else — WiFi/BLE if needed, sleep/wake timing and power-sequencing logic, receiving the K210's inference result over UART, packaging that result into a LoRa packet, and handing it to the LoRa radio for transmission

This division is why, in the power design (Part 4), the ESP32 is the component trusted to manage deep sleep, while K210 is treated as a power-hungry peripheral that gets fully power-gated (switched off entirely, not merely "slept") between active bursts.

### 3.4 The modular mainboard + daughterboard architecture

The final hardware pattern adopted, connecting back to prior work on a general-purpose modular edge AI dev board: one core mainboard (compute + power management + LoRa comms — either an ESP32-S3-only "lite" tier, or an ESP32+K210 "vision" tier) paired with swappable daughterboards carrying only the hazard-specific sensor hardware, connected via a standardized pinout exposing I2C, a couple of ADC-capable analog pins, and power.

Water/flood daughterboard: camera module (primary) plus a tipping-bucket rain gauge (specific parts: YL-83 rain sensor for a cheap hobbyist version, or Davis 7852 rain collector for an industrial-grade, more accurate option) as a supplementary upstream-rainfall leading indicator that the camera structurally cannot capture.

Fire/forest daughterboard: camera module (primary, potentially shared with water sensing), plus the YG1006 IR flame sensor as a low-power wake trigger.

Seismic/landslide daughterboard: MPU6050 (baseline) or ADXL355 (upgrade path) accelerometer as primary, plus SCA100T-D02-class tilt sensor and capacitive soil moisture sensor v1.2 as supplementary precursor signals — this board is explicitly camera-free.

Shared across all daughterboard types: a simple resistor-divider circuit into an ADC pin for battery voltage monitoring (not a discrete purchasable sensor, but a required circuit on every variant, since battery health reporting is load-bearing for the power-degradation detection logic in Part 4).

An open engineering decision explicitly left to the team: whether to standardize on one universal mainboard (sized for the heaviest case, K210-class, used even on nodes that don't strictly need it — simpler to manufacture/test, but wastes cost and power on lighter-duty nodes)

versus two mainboard tiers (ESP32-S3-only "lite" and ESP32+K210 "vision," sharing the same daughterboard connector standard — more efficient per-node economics, at the cost of double the mainboard design and validation effort).

### 3.5 Physical/mechanical considerations

Camera lens maintenance was identified as a real, non-trivial field-reliability risk — a system that reads perfectly on a spec sheet but silently fails after the lens gets muddy, algae-covered, or obstructed by debris/insects/frost is not meaningfully "deployed." The layered mitigation strategy adopted, in priority order:

1. Physical prevention (free, mechanical): a downward-angled rain/sun hood shielding the lens from direct splash and precipitation, plus mounting position chosen to avoid normal splash zones
2. Self-detection of degraded readings: firmware logic that checks image contrast/sharpness against an expected baseline and flags "sensor obstructed" as its own distinct status message, converting a silent failure into a known, actionable one — this is treated as more important than solving the cleaning problem itself, since visibility into a fault is what allows a response
3. Scheduled human maintenance visits accepted as a normal, expected part of the operating model (analogous to how real weather stations and wildlife cameras are maintained), rather than treated as a design failure requiring elimination
4. Active mechanical cleaning mechanisms (wipers, air-puff systems) explicitly deprioritized as unnecessary added complexity, failure points, and power draw for this project stage

PART 4: POWER SYSTEM — FULL DERIVATION

### 4.1 The governing design requirement: autonomy days, not average-case power

The critical reframe established: the correct sizing target is not "power the node on a typical day," but "survive N consecutive days of near-zero solar input without failing." This is the standard concept of autonomy days in off-grid solar system design. For a monsoon-heavy mountain deployment, extended overcast stretches of one to two weeks are a realistic design case, not a rare tail event, and the system must be sized against this explicitly.

### 4.2 State-based current draw model

Total energy consumption is modeled as the sum of time spent in each operating state multiplied by that state's current draw, rather than a single average figure — because the dominant driver of total power budget is how aggressively the system can power down between active periods.

States identified for a camera+K210 node:

- Deep sleep: target microamp-to-low-milliamp range, contingent on whether K210 can be fully power-gated (see 4.3)
- Wake + camera initialization: brief transitional current spike as the camera sensor rail powers up (roughly 80-150mA range, for 1-2 seconds)
- Active capture + KPU inference: the peak-draw state, roughly 200-300mA estimated, sustained for only 1-3 seconds per wake cycle
- LoRa transmit: roughly 120mA for a routine packet, momentarily higher during transmission bursts, sustained under 1 second

At a wake interval of every 5-15 minutes (900 seconds, using 15-minute cycles as the worked example), the node spends the overwhelming majority of each cycle — roughly 895 of 900 seconds — asleep, and only 3-5 seconds active. This means average power draw is dominated by sleep-state current, not by the K210's active power appetite, provided sleep is genuinely deep.

### 4.3 The critical unresolved variable: K210 sleep current

A key finding from direct research: Kendryte's own public documentation does not state a verified, trustworthy sleep-mode or active-mode current figure in milliamps for the K210. Marketing materials describe it generically as "low power," and the one concrete number found in official board documentation (a Sipeed MaixGo board recommendation of greater than 600mA supply current) is a board-level active-operation supply sizing recommendation — not a chip-level sleep-mode specification.

Because this number cannot be safely assumed, the adopted engineering default is: do not rely on K210's own claimed sleep mode. Instead, use the ESP32 (whose deep-sleep current is well-documented at the microamp level, a mature and trusted specification) to fully power-gate the K210 and camera rail using a MOSFET or dedicated load switch between the two chips' shared power rail and the battery. The ESP32 wakes on its own low-power hardware timer, switches power ON to the K210+camera circuit only for the duration of the active capture-and-inference burst, then cuts that rail's power entirely (not merely idling it) before returning to its own deep sleep. This makes the system's power budget independent of an unverified number: a fully power-gated K210 draws exactly zero current when its rail is switched off, regardless of what its internal "sleep mode" would have consumed if left powered.

This measurement is flagged as the single most important unresolved action item: physically measuring real current draw (active state, K210's own claimed sleep state, and fully power-gated/off state) using a multimeter or inline USB power meter on actual hardware, since this single measured value determines whether battery-sizing math holds as calculated or needs significant revision.

### 4.4 Worked daily energy budget (illustrative, pending real measurement)

Using estimated figures at 15-minute wake cycles (96 wake events per 24-hour day):

- Sleep contribution: approximately 23.9 hours at an estimated ~5mA average ≈ 120 mAh

- Active-burst contribution: 96 wakes × ~5 seconds average active duration × ~250mA average current ≈ 96 × 0.35 mAh ≈ 33 mAh
- Total estimated daily energy requirement: approximately 150-180 mAh per day (at the board's ~5V regulated rail), equivalent to roughly 0.75-0.9 Wh/day

### 4.5 Autonomy-based battery sizing

Applying the 150-180 mAh/day figure (≈0.9 Wh/day) against a target of surviving extended dark stretches:

- 7 days autonomy: raw requirement ≈1,260 mAh; applying a realistic 1.5-2x safety margin for battery inefficiency, depth-of-discharge limits, and estimation uncertainty in the underlying current figures → practical target of 2,000-2,500 mAh
- 10 days autonomy (the explicitly stated worst-case planning target): raw requirement ≈150 Wh over 10 days at 0.625W average power (using the mesh-always-listening scenario developed in 4.7) → at 12V nominal, this corresponds to roughly a 12.5 Ah battery, with a recommended real-world target of 15-20 Ah once margin is applied for cold-temperature capacity derating and estimation uncertainty
- 14 days autonomy: roughly double the 7-day figure, in the 4,000-5,000 mAh range at the lower voltage baseline, or proportionally scaled at 12V

### 4.6 Voltage architecture

The Maixduino board's own specification calls for 6-12V DC input, internally regulated down to 5V at up to 1.2A via its own USB-C step-down circuit. This drove the recommendation of a 12V nominal battery system, specifically LiFePO4 chemistry rather than standard Li-ion/LiPo, for the following reasons:

- Substantially better cold-temperature tolerance and rechargeability — directly relevant given likely cold nights/winter conditions at Himalayan-region deployment sites, where standard LiPo capacity and cycle life degrade meaningfully
- Much longer cycle life (typically 2,000-5,000+ charge cycles versus roughly 500-1,000 for standard Li-ion), relevant for a system intended to run unattended across multiple years without battery replacement
- Materially safer chemistry, with much lower thermal runaway/fire risk than standard LiPo — a meaningful consideration for unattended field hardware
- Trade-off accepted: LiFePO4 is physically larger and heavier per watt-hour of stored energy than LiPo, and typically costs more upfront

A buck converter/step-down module (specifically recommended: a 12V-to-5V or 12V-to-9V DC-DC buck converter module) was recommended as a safety buffer between a nominally-12V LiFePO4 pack (which can read as high as 13-14.6V when fully charged) and the Maixduino's input, to guarantee the board never sees voltage above its rated maximum input even at full charge.

### 4.7 The mesh-always-listening scenario — a critical late-stage revision

A major reframe emerged from the requirement that LoRa mesh relaying requires nodes to forward other nodes' packets, meaning the radio and its controlling MCU cannot be fully asleep on the same schedule as the sensing subsystem — a sleeping relay node cannot receive and forward a packet passing through it.

This was resolved by explicitly separating two independent power domains within a single node:

Domain A — mesh relay function (ESP32 + LoRa radio): must remain continuously listening. Estimated continuous draw: ESP32 active (~80-160mA) + LoRa radio in receive/listen mode (~10-15mA) ≈ roughly 112-130mA continuous.

Domain B — sensing function (camera + K210): can remain on its own independent sleep/wake schedule (every 5-15 minutes), power-gated per section 4.3, regardless of Domain A's continuous operation.

Two scenarios were explicitly modeled and compared:

- Scenario A (correct design): only Domain A (radio/ESP32) stays continuously on; Domain B still sleeps normally → average draw approximately 115-130mA continuous, translating to roughly 5.6 days of runtime on a 7Ah battery, or roughly 16 days on a 20Ah battery, with zero solar input
- Scenario B (rejected design): everything, including camera and K210, held continuously active with no sleep at all → average draw balloons to approximately 440mA continuous, translating to only about 1.6 days of runtime on a 7Ah battery, or roughly 4.5 days on a 20Ah battery — incompatible with any multi-week unattended operation goal regardless of how large a battery is used

Explicit recommendation: never disable sleep for the entire node. The mesh-relay radio function must stay listening continuously as a hardware/protocol necessity, but the camera/K210 sensing subsystem should retain its independent sleep schedule regardless, since there is no networking requirement forcing it to run continuously. This hybrid approach is what keeps a 12V solar+battery system viable at all.

### 4.8 Contingency and graceful degradation beyond fixed battery sizing

Beyond static battery capacity, three additional resilience layers were identified:

Adaptive wake-interval throttling: firmware logic where the node monitors its own battery voltage (already required for the standard telemetry packet) and automatically extends its wake interval — for example, stretching from a normal 10-minute cycle to 30-60 minutes — once voltage drops below a defined threshold, trading responsiveness for extended survival specifically during an extended dark stretch, allowing the system to degrade gracefully rather than fail outright. This logic mirrors, at the node level, the same battery-voltage field already transmitted to the hub for network-wide monitoring.

Hybrid/complementary generation sources (proposed as forward-looking, differentiated design, not required for the initial build):

- Wind: compact off-grid wind turbines suited to remote-sensor scale, justified by the observation that overcast conditions and low wind don't necessarily correlate — a cloudy but windy stretch could still provide charging via a combined solar+wind charge controller
- Micro-hydro: given the nodes' inherent proximity to flowing water, small in-stream micro-hydro generators (designed for low-flow-rate, small-scale off-grid sensor applications) could provide charging largely independent of weather, since river flow tends to be far more consistent than sunlight in a monsoon-adjacent region — explicitly flagged as a differentiated pitch point specific to this project's deployment context
- Primary (non-rechargeable) backup cells: a small industrial lithium primary cell (e.g., LiSOCl2 chemistry, as used in remote utility meters for extremely long shelf life and low self-discharge) wired as a last-resort failsafe that only engages if the main rechargeable battery drops below a critical voltage floor

### 4.9 Recommended concrete components (for sourcing)

- Battery: 12V LiFePO4 pack, 15-20Ah capacity — search terms: "12V LiFePO4 battery 15Ah/20Ah," brands referenced: Redway, Renogy, Zeus, Loom Solar (India-based)
- Charge controller: a controller explicitly rated for LiFePO4's charge voltage profile (not all controllers support this chemistry correctly) — search: "12V solar charge controller LiFePO4," brands referenced: Victron (higher-end), EPEVER, Renogy; MPPT preferred over PWM for 5-20% better charging efficiency, particularly valuable given cloudy/low-light mountain conditions
- Solar panel: monocrystalline, 10-20W, 12V nominal output — search: "12V 10W/20W monocrystalline solar panel," brands referenced: Loom Solar, Luminous, Waaree; must be explicitly rated IP65 or higher for weather exposure, with an aluminum frame (for secure pole-mounting against wind) and a pre-wired junction box (not bare terminals)
- Buck converter: search: "DC-DC buck converter 12V to 5V/9V 3A" — as the voltage-safety buffer described in 4.6

For the immediate 3-day hackathon demo specifically, a simpler standard 12V 7Ah sealed lead-acid or basic Li-ion pack (readily available same-day) was recommended as sufficient for demonstration purposes, with the full LiFePO4/MPPT/monocrystalline specification explicitly documented as the researched production-deployment plan rather than something that needed to be sourced and tested within the demo timeframe.

PART 5: THE PREDICTION ALGORITHM — FULL LOGIC

### 5.1 Where each computation happens, and why

A foundational architectural decision: individual nodes do not retain their own historical data or compute their own baseline. This was deliberately settled after examining the memory/persistence problem directly — if a node's K210 is power-gated off between cycles (per Part 4.3), any data sitting in its RAM is lost the instant power is cut, meaning cross-cycle statistical memory cannot live in node RAM at all.

Rather than solving this with local flash/SD-based persistence on each node (a viable but more fragile alternative — subject to flash wear, physical failure, or loss if a node is replaced), the design deliberately centralizes all historical memory and cross-node reasoning at the hub, for these reasons:

- The hub never loses power the way a sleeping/power-gated node does
- Historical memory shouldn't be tied to a single physical node's local storage surviving intact, especially given the OTA re-flashing capability that might involve replacing node hardware
- Cross-node correlation is structurally impossible to compute on any single node, since no individual node has visibility into any other node's readings — this reasoning can only happen at a point that receives data from multiple sources, which is the hub by definition

This means each node's actual job, restated precisely: wake, read sensor(s), compute the current frame's features (turbidity, turbulence, coverage, or accelerometer/tilt/moisture readings, depending on hazard type), transmit those raw current-cycle values, and return to sleep. No local statistics, no local history, no local decision-making about whether to alert.

### 5.2 The rolling baseline — mathematical formulation

For each node, the hub maintains a rolling window of that node's historical readings (recommended trailing window: on the order of 30 days, chosen to be long enough to smooth out daily noise while still adapting to genuine seasonal drift, such as the transition into monsoon season).

For each feature type (e.g., turbidity), the hub computes:

- Rolling mean (μ): the average value of that feature over the trailing window
- Rolling standard deviation (σ): the spread/variability of that feature over the same window

A new incoming reading is then evaluated not against a fixed number, but against a z-score-style deviation measure: how many standard deviations away from this specific node's own recent mean does the new reading fall? A commonly cited example threshold discussed was flagging deviation when a reading falls 3 or more standard deviations above the rolling mean — a statistically significant departure from that site's own established normal, regardless of what that site's absolute baseline numbers happen to be.

This is what allows the exact same escalation logic to correctly handle a gently flowing lowland river and a fast mountain torrent without any manual per-site calibration: each node's "abnormal" is defined relative to its own accumulated history, not a shared constant.

### 5.3 Rate of change as the primary signal, not absolute value

A specific refinement established during the design process: rate of change is a more portable and more genuinely predictive signal across different rivers than absolute feature values. A flood surge produces an unusually fast rise relative to that river's own typical behavior, regardless of whether that river's baseline sits at a low or high absolute value. This makes rate-of-change deviation (the first derivative of a feature over time, compared against that node's historical rate-of-change distribution) the primary quantity the escalation logic watches, with absolute-value deviation serving a secondary, confirmatory role.

### 5.4 Cross-node correlation and travel-time estimation

This is identified as the actual mechanism that produces genuine predictive lead time, and it is explicitly a network-level property that no single node's sophistication can substitute for.

The logic: when an upstream node's reading deviates significantly from its own baseline (per 5.2), the hub does not immediately escalate to a full alert. Instead, it checks whether the same relative deviation pattern subsequently appears at the next node downstream, within a time window calculated from the known physical distance between the two nodes and a reasonable estimate of the river's typical flow speed at that reach.

This travel-time estimate is basic kinematics: time = distance ÷ velocity. The distance between any two nodes is known precisely because of the geotagging mechanism (Part 7): each node's physical GPS coordinate is captured at deployment time and stored against its unique node ID, allowing the hub to compute real inter-node distances directly. The flow-velocity estimate would be refined over time using the project's own accumulated dataset (correlating how long it actually took a known event to propagate between two specific nodes in the past), making the propagation-time estimate itself improve as more real seasonal data accumulates — directly tying back to the project's dataset-building value.

If the expected downstream deviation is confirmed within the calculated travel-time window, confidence in a genuine, propagating flood event increases substantially, and the hub can issue an alert to communities further downstream with a stated estimated arrival time — this is the concrete mechanism that produces actionable lead time (potentially hours), rather than the single-point, immediate-only warning a detector-style system would give.

### 5.5 Why the escalation logic is rule-based, not a black-box learned model

An explicit design principle: given that this is a life-safety system where false negatives (missed real floods) carry severe consequences, the escalation decision logic (baseline comparison, rate-of-change thresholding, cross-node correlation, travel-time estimation) is implemented as transparent, auditable, rule-based logic rather than an opaque trained model making the final call. This is consistent with how real operational flood-forecasting systems (referenced: India's Central Water Commission) function at the operational level — level, rate-of-change, and upstream correlation logic, rather than deep learned prediction — specifically because such systems must be explainable and every decision must be traceable to a specific, inspectable cause.

A learned predictive layer was explicitly discussed as a legitimate future enhancement, to be layered on top of the rule-based system once a real season or more of accumulated historical data exists — but positioned as an addition that refines the rule-based system's judgment, not a replacement for it, preserving auditability.

PART 6: MACHINE LEARNING PIPELINE — FULL DETAIL

### 6.1 The distinction between "the model" and "the firmware," clarified precisely

A key conceptual clarification made explicit: a trained neural network model is not, by itself, a runnable program. It is a set of learned numeric weights plus an architecture definition. Running it on a K210 in the field requires a separate firmware program (written in MicroPython via MaixPy, or in C using Sipeed's official SDK) that handles everything around the model: waking from sleep, initializing the camera, capturing a frame, invoking the model as a single function call (loading the compiled model file and feeding it the captured frame), interpreting the resulting confidence score against a decision threshold, packaging the result, and handing it off for transmission before returning to sleep. The model is one function call inside a larger firmware program — not the entire program.

### 6.2 The full pipeline, step by step

Step 1 — Task definition: define the exact classification task as narrowly as useful. For fire detection, the recommended starting scope is strictly binary — "fire/smoke present" versus "normal scene" — deliberately avoiding a more complex multi-class scheme (fire vs. smoke vs. haze vs. clear) until the simpler binary version is validated, since a narrower task requires less training data and is easier to evaluate correctly. This step also requires explicitly defining hard negative cases in advance — sunsets, orange-colored objects, vehicle lights — the deliberate false-positive traps that a naive color-based approach would fail on.
Step 2 — Dataset collection and labeling: the identified bottleneck of the entire pipeline, more time-consuming than any subsequent step. Public datasets identified as strong starting points:
- Roboflow's Fire Detection dataset — approximately 9,000 annotated images specifically distinguishing active flames and smoke plumes from non-threatening environmental factors like sunsets and orange objects, directly addressing the false-positive concern from Step 1

- The Flare Guard GitHub project (repository: sayedgamal99/Real-Time-Smoke-Fire-Detection-YOLO11) — 10,463 annotated images plus a complete working reference pipeline (training, detection, and alerting via messaging integration) usable as a structural template even though it targets YOLO11/GPU deployment rather than K210 directly
- For flood/water: a GitHub repository (duchieu260503/Flood-detection) implementing YOLOv8 segmentation to detect water extent, plus the actual mathematics to convert detected pixel position to real-world water level using a physical reference stick visible in frame with two known calibration points — identified as the closest existing reference to the project's own gauge-reading concept
- The FloodIMG dataset (published research, 9,200+ images with bounding boxes and severity/depth scoring) and the RIWA river water segmentation dataset as additional flood-specific resources
- Explicit finding: no pre-trained, ready-to-deploy K210-format fire or flood detection model exists publicly — what exists is mature tooling for training your own quickly, not a plug-and-play solution, because these are narrow, deployment-specific tasks where a model trained on someone else's camera angle and lighting conditions transfers poorly to a new site (the same underlying reasoning that motivates the per-site baseline-learning approach in Part 5, applied here to vision model generalization)
- Labeling tools referenced: LabelImg or Roboflow's own labeling interface
Step 3 — Dataset splitting: standard machine learning practice of dividing labeled data into training (approximately 70%), validation (approximately 15%), and test (approximately 15%) subsets — training data is what the model learns from, validation data checks progress during development without contaminating the final evaluation, and test data is held back completely until the very end to produce an honest, unbiased accuracy figure.
Step 4 — Architecture selection: use a proven, lightweight, K210-compatible architecture rather than designing one from scratch or reaching for a large/exotic model. Specifically recommended: MobileNetV1 or MobileNetV2, or a small custom CNN, chosen because Kendryte's nncase conversion toolchain has known, well-tested support for these architecture families — an exotic or very recent architecture risks failing the later conversion step entirely, wasting significant time. Transfer learning (starting from ImageNet-pretrained weights and fine-tuning only on the project's own dataset) is recommended over training from randomly initialized weights, since it requires substantially less data and training time to reach good accuracy.
Step 5 — Training: implemented in Python using TensorFlow/Keras (preferred over a PyTorch-based path for this specific hardware target, since nncase's TensorFlow Lite input support is more mature than its ONNX/PyTorch path). Training script structure: load labeled images, apply data augmentation (random brightness, rotation, and cropping to improve robustness to real-world lighting/framing variation), then fine-tune the pretrained MobileNet-class model on the project's labeled dataset. This step runs entirely on a standard PC/laptop with a GPU and has no direct connection to the K210 yet — it is conventional ML training.

Step 6 — Honest evaluation: assess the trained model against the held-out test set, with explicit attention to the confusion matrix, not just overall accuracy — specifically the false-negative rate (real fires/floods missed) versus the false-positive rate (false alarms). Given this is a life-safety system, the design principle established is that missed real events are categorically worse than false alarms, which may justify deliberately shifting the decision threshold to favor catching more true positives even at the cost of more false alarms, with this tradeoff explicitly verified against the test set rather than assumed.
Step 7 — Quantization and conversion for K210: the trained Keras model is first converted to TensorFlow Lite format, then processed through nncase (Kendryte's official model conversion toolchain), which quantizes the model (reducing numeric precision from 32-bit floating point to 8-bit integers, a requirement of the KPU hardware) and compiles it into the K210-native .kmodel file format. This step is explicitly flagged as prone to needing iteration, since quantization can noticeably reduce accuracy — the recommended practice is to re-test the quantized model's accuracy against the test set again after conversion, not to trust the pre-quantization accuracy figure as final. A training framework called aXeleRate was identified as a tool that automates much of this training-to-conversion pipeline specifically for K210 targets, including a documented reference tutorial (a "raccoon detector" project) demonstrating the full flow from labeled images through automatic .kmodel conversion and even streaming inference results over UART — directly analogous to the project's own node-to-ESP32 handoff pattern.
Step 8 — Deployment and real-hardware validation: load the final .kmodel onto the K210 via the node's actual firmware, and test using the real camera in its real mounting position — since lab-tested performance often diverges from field performance due to the specific lens characteristics, lighting conditions, and image artifacts unique to the deployed hardware. This is also where firmware-level decision logic is tuned and validated — for instance, requiring multiple consecutive positive detections across successive frames before triggering an alert, to guard against a single-frame false positive triggering an unnecessary escalation.

### 6.3 GPU training time estimates (RTX 3050 vs RTX 4090)

For the roughly 9,000-image fire dataset, using transfer learning on a MobileNet-class architecture:

- RTX 3050 (6GB VRAM): raw training time of roughly 30-90 minutes per run for approximately 20-30 epochs, with realistic total hands-on iteration time (including 2-4 rounds of adjustment and retraining based on evaluation results) spanning roughly half a day to a full day
- RTX 4090 (24GB VRAM): raw training time compressed to roughly 5-15 minutes per run, a 5-8x speedup from dramatically higher CUDA core count, memory bandwidth, and available VRAM allowing larger batch sizes; total realistic hands-on iteration time compressed to roughly 2-4 hours
- Critical caveat established in both cases: GPU choice has no effect on dataset collection/labeling time, the human-judgment-driven evaluation and threshold-tuning loop, the CPU-bound nncase quantization/conversion step, or real-hardware validation on actual K210 hardware — these remain the dominant time costs regardless of training GPU, meaning a faster GPU compresses iteration speed but does not proportionally compress the project's overall timeline

PART 7: COMMUNICATION — LORA MESH IN DETAIL

### 7.1 Why LoRa, and why not alternatives

Cellular and WiFi connectivity is unreliable to entirely absent in mountain and river-valley terrain, ruling out both as primary long-range links. LoRa (Long Range radio) was selected specifically because it provides long-range communication (kilometer-scale under good line-of-sight conditions) at very low power draw, operating in a license-free ISM radio band, making it suitable for battery/solar-powered nodes with no ongoing connectivity cost.

### 7.2 Frequency band selection

433 MHz (a sub-GHz band, license-free in India) was selected over the 868/915 MHz LoRa variants specifically because lower-frequency radio waves penetrate terrain features and foliage more effectively — directly relevant given the mountain valley and forest deployment context, where higher-frequency signals would suffer greater obstruction loss.

### 7.3 Mesh topology, not star topology

A star topology (every node communicating directly to one central gateway) was explicitly rejected in favor of a multi-hop mesh, because mountain terrain (valleys, ridgelines) will routinely break direct line-of-sight between a distant node and a single fixed gateway location. In a mesh, nodes relay packets through intermediate neighboring nodes toward the gateway, tolerating the loss of any single direct path. Dedicated relay-only repeater nodes (carrying no sensors at all, just a LoRa radio, ESP32, and solar/battery power) were proposed as a solution for geographic gaps where sensing nodes alone don't provide adequate mesh connectivity, and elevated/ridge-advantaged mounting positions were noted as dramatically extending usable LoRa range even with a small elevation gain.

### 7.4 Message format specification

Given LoRa's inherently small payload capacity (typically in the range of 50-250 bytes depending on the spreading factor configuration used), the message format is a compact fixed-layout binary structure, explicitly not JSON or any text-based/self-describing format, to minimize airtime and power cost per transmission:

[node_id: 1 byte][timestamp: 4 bytes][msg_type: 1 byte]
[primary_reading: 2 bytes][rate_of_change: 2 bytes]
[battery_mv: 2 bytes][secondary_flag: 1 byte][checksum: 1 byte]

Total: approximately 14 bytes per packet. The msg_type field distinguishes at minimum between routine status updates (transmitted on a fixed schedule, e.g., every 5-15 minutes) and priority alerts (transmitted immediately upon detection of a significant deviation, outside the normal schedule) — allowing the hub's software to prioritize processing of alert-type packets. A checksum byte is included for basic data integrity verification given the inherent unreliability of long-range radio links. Raw high-resolution data — full camera frames, extended sensor logs — is explicitly never transmitted over LoRa due to payload size constraints; this data remains local to the node (stored on SD card) and is retrieved manually or during scheduled maintenance visits, serving the project's separate long-term dataset-building goal.

PART 8: THE CENTRAL HUB — SOFTWARE ARCHITECTURE

### 8.1 Hardware progression

Development/prototyping phase: a standard laptop, chosen deliberately over a Raspberry Pi at this stage specifically for faster iteration — full Python tooling (pandas, scikit-learn, standard debugging environments) without the friction of developing on constrained embedded hardware.

Field deployment phase: migration to a Raspberry Pi (4 or 5) once the correlation and escalation logic has been validated, chosen for its ability to run unattended for extended periods with modest power draw, appropriate for a system that itself needs solar/battery power at a field-deployed gateway location.

### 8.2 Software responsibilities, in full

The hub is the only component in the entire system with persistent, cross-node, cross-time memory, and its responsibilities are correspondingly the parts of the system that are structurally impossible to push down to individual nodes:

1. Packet ingestion and parsing: receiving raw binary LoRa packets via a gateway radio module (referenced specific parts: SX1276 or RFM95-based LoRa modules connected via UART/SPI to the Pi), decoding the fixed binary structure from Part 7.4 into structured data
2. Persistent historical storage: every parsed reading, from every node, is logged with a timestamp into a database (specifically referenced: SQLite for structured queryable storage, or plain CSV for simpler logging) — this accumulating store serves double duty as both the operational memory needed for baseline computation (Part 5.2) and as the project's long-term research dataset asset
3. Rolling baseline computation (Part 5.2): maintained per node, per feature type, continuously updated as new readings arrive
4. Cross-node correlation and travel-time estimation (Part 5.4): the core predictive computation, requiring the full multi-node dataset described above

5. Escalation decision logic (Part 5.5): the final rule-based determination of whether, and how urgently, to issue an alert
6. Alert dispatch: triggering the SMS notification pipeline (Part 9)
7. Node health monitoring: tracking battery voltage trends per node (from the telemetry field already present in every packet) to flag nodes showing sustained decline as an operational maintenance signal, distinct from the hazard-detection alerting pipeline

### 8.3 Why the hub, not the node, despite "most processing happening on the node"

Directly addressing the apparent tension: even with substantial feature-extraction computation happening on-node (turbidity/turbulence/coverage calculation, or accelerometer signal processing), the hub's role is not diminished, because its function is categorically different from a node's. Nodes compute a single current reading. The hub's entire value is built from holding history across time and correlating across independent physical locations — neither of which a resource-constrained, intermittently-powered, single-location node can do by itself, regardless of how much on-node compute capability it has. The Raspberry Pi's suitability for this role comes not from raw inference throughput (which it comparatively lacks versus a K210's dedicated KPU) but from its capacity for persistent storage, multi-source data fusion, and continuous operation, which are the genuinely hub-specific requirements.

PART 9: ALERTING MECHANISM — SMS DISPATCH

### 9.1 Two fundamentally different technical approaches

Cell broadcast (mass alert to all phones in a geographic area, by tower coverage, not by known phone number): this is how real government-level emergency alerts function, implemented in India through the NDMA's Common Alerting Protocol (CAP), delivered via the Integrated Alert System / SACHET platform, working through direct telecom operator integration. This approach was explicitly identified as not independently buildable within this project's scope, since it requires authorized government/disaster-authority status and direct telecom operator agreements — appropriately documented in project materials as "designed to integrate with NDMA's SACHET/Cell Broadcast system" as a future-scope/integration target, rather than a built feature.

Registered-number SMS dispatch (buildable now): a database mapping specific phone numbers to specific geographic zones or node coverage areas, built through a registration process (community sign-up, local administration coordination). When the hub's escalation logic fires an alert tied to a specific node, it queries the registration database for numbers associated with that node's zone (and, per the travel-time model in Part 5.4, potentially the zones of downstream nodes within the estimated arrival window), then dispatches SMS to that specific, known list.

### 9.2 Physical SMS dispatch mechanism

For actual message transmission, two options were evaluated:

- A GSM module with a local SIM card (specific parts referenced: SIM800L or SIM7600) connected directly to the hub hardware — sends SMS directly to the cellular network without requiring internet connectivity at the hub, which aligns well with the project's low-connectivity mountain deployment assumption. Noted limitation: sends messages roughly one at a time with several seconds per message, adequate for hundreds of recipients but comparatively slow for very large recipient lists
- A cloud SMS API service (referenced: Twilio, MSG91, Fast2SMS for the Indian market) — offers much faster bulk sending, but requires the hub itself to have internet connectivity, which may not hold if the hub is deployed at the same remote, low-connectivity location as the sensor nodes it serves

Recommendation: the GSM-module approach is more architecturally consistent with the project's mountain-deployment constraints, particularly if the hub sits at a location with cellular signal even where individual sensor nodes do not.

### 9.3 Zone-based versus dynamic geofencing for recipient selection

The simplest implementable version assigns each registered phone number to its nearest node/zone at registration time, with an alert for that node (or nodes calculated to be upstream within the propagation model) triggering SMS to everyone registered in that zone. A more sophisticated future-scope version would use registered precise GPS coordinates per number and dynamically calculate real distance against the live flood-propagation estimate to decide recipients in real time — explicitly noted as adding meaningful complexity (geofencing computation, ongoing user location data requirements, associated privacy considerations) beyond the zone-based version's scope.

PART 10: OPERATIONAL/DEPLOYMENT LAYER

### 10.1 Remote firmware updates via a companion phone app

A mobile app connects to a deployed node via USB (using Android's USB-OTG/serial capability), replicating the function of standard desktop flashing tools for each chip family (an esptool-equivalent flow for ESP32, a kflash-equivalent flow for K210). The app downloads the correct firmware binary — tagged by node type and version (e.g., a naming convention like flood-v1.2.bin) — from a cloud server, flashes it to the connected device, and critically, verifies successful boot and correct version reporting before marking the update as successful, specifically to avoid a scenario where a field-flashed device is left bricked with no easy recovery path, given the practical difficulty of a return visit to a remote mountain site.

### 10.2 Node geotagging at deployment

At the moment of physical installation (explicitly distinguished from the moment of firmware flashing/preparation, which may happen earlier at a workshop, away from the final site), the app captures the phone's own GPS coordinate — not a GPS module on the node itself, since duplicating GPS hardware on every node would add unnecessary cost and power draw when the deploying technician's phone already provides an equivalent one-time coordinate — and pushes this location to a cloud database (referenced: AWS), tagged against that specific node's unique hardware ID.

This stored node-ID-to-location mapping is what allows the central hub to compute real physical inter-node distances, which is a direct input to the travel-time propagation estimate described in Part 5.4 — without accurate geotagging, the hub's correlation logic would have no basis for estimating how long a detected upstream event should take to reach a downstream node.

PART 11: FUTURE-SCOPE ITEMS EXPLICITLY DOCUMENTED (NOT BUILT)

For completeness and honesty in project framing, the following were identified as legitimate, researched extensions explicitly scoped as future work rather than components of the current build:

- A tiered dashboard product for government/disaster-authority officials, structured as a free base tier (live node status, real-time alerts, basic map view, historical alert log — deliberately kept free and unconditional since gating actual life-safety alerts behind payment was identified as both ethically wrong and reputationally damaging) plus a paid premium tier (trend/seasonal analytics, cross-node correlation visualizations, multi-site administrative management, custom threshold tuning, data export/API access, integration hooks into existing government emergency broadcast systems)
- Cell-broadcast/NDMA SACHET integration for true mass geographic alerting, as distinct from the registered-number SMS approach that is independently buildable
- Wind and micro-hydro supplementary power generation, as detailed in Part 4.8
- Two-tier mainboard standardization (lite ESP32-S3 versus full K210 vision tier) as an open cost/engineering-effort decision
- A learned predictive model layered atop the rule-based escalation logic, to be developed once sufficient real seasonal historical data has accumulated through the system's own operation

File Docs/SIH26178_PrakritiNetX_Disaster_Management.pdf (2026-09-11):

# SMART INDIA HACKATHON 2026

# - Problem Statement ID -

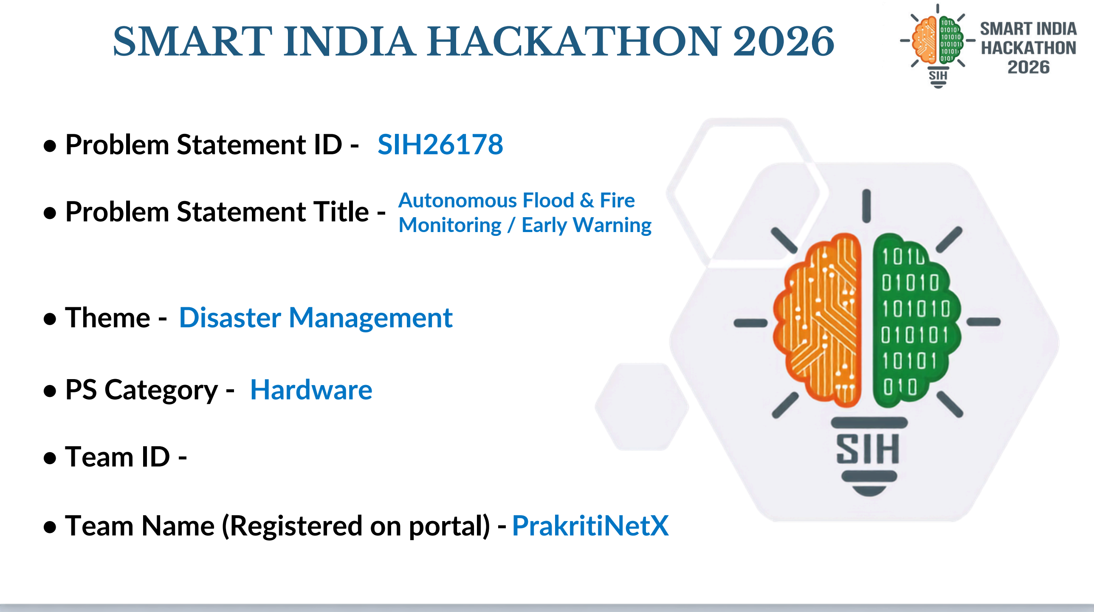
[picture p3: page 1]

# - PS Category -

# - Team ID -

# - Team Name (Registered on portal) -

# SIH26178

# - Problem Statement Title -

## Autonomous Flood & Fire Monitoring / Early Warning

# - Theme - Disaster Management

# Hardware

SIH

# PrakritiNetX

P

r

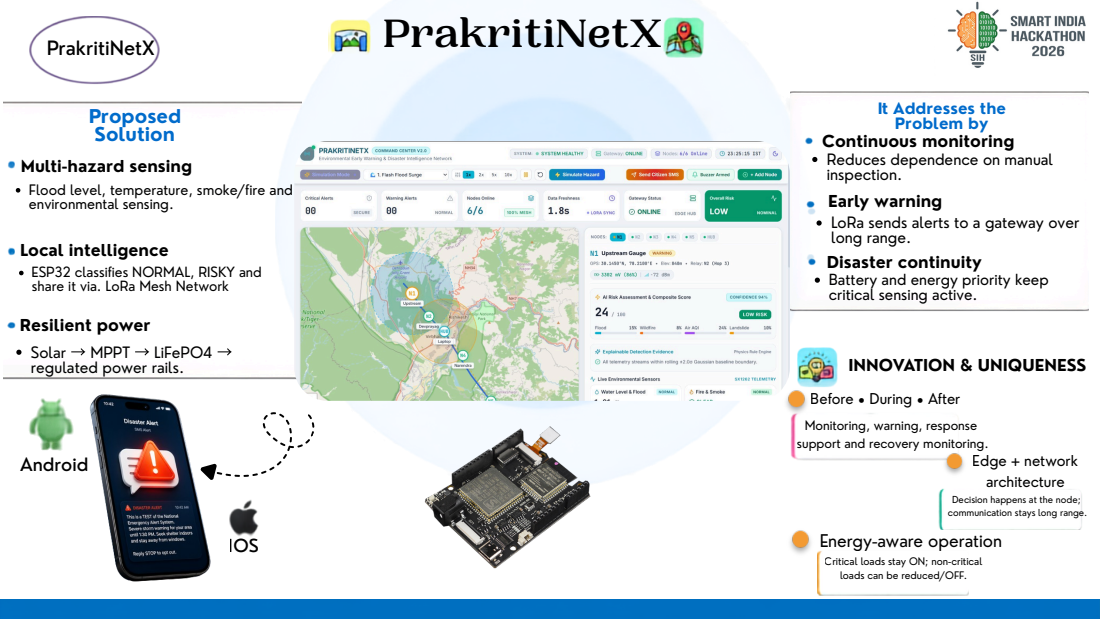
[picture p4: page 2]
sifie; RIS; via; LiF; ail; Local in; telligenc; Resilient po; wer; Continuous monitoring; Early warning; Disaster continuity; INNO; VATION & UNIQUENESS; cisio; nic; tio; nit; rin; nin

l inspection. Battery and energy priority keep critical sensing active.

Multi-hazard sensing

## Tech Stack

# TECHNICAL APPROACH

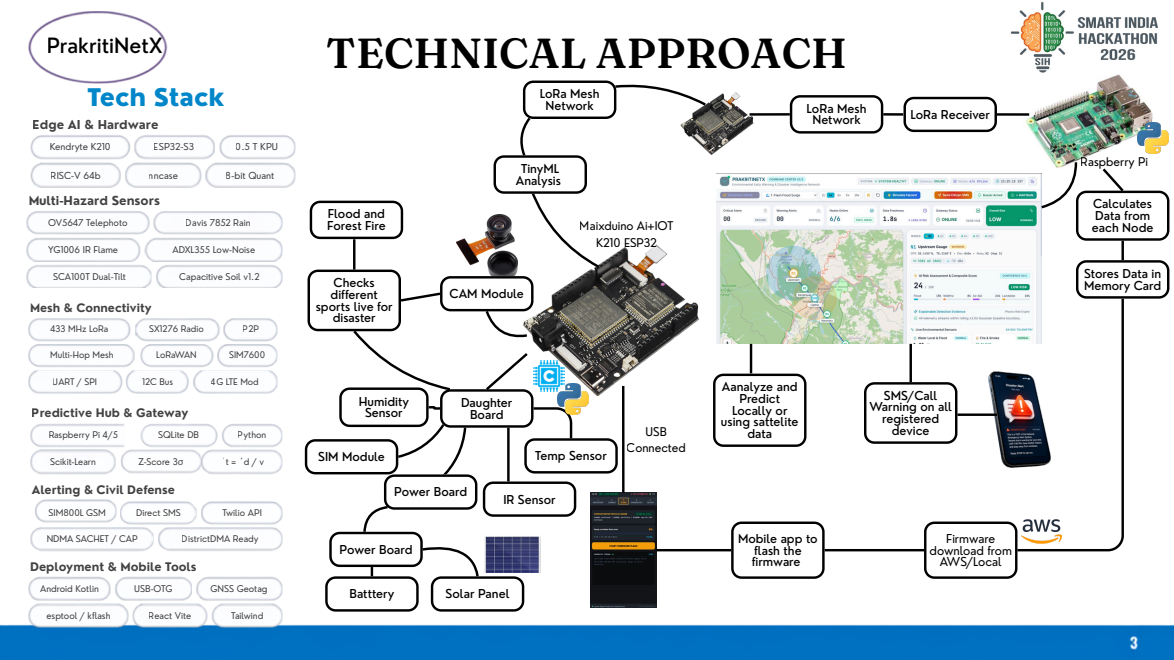
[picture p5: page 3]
Firmware download from AWS/Local; Daughter Board; CAM Module; Temp Sensor; Humidity Sensor; SIM Module; TinyML Analysis; Flood and Forest Fire; LoRa Mesh; Network; LoRa Receiver; Calculates Data from each Node; Power Board; Batttery; Solar Panel; Raspberry Pi; Aanalyze and Predict Locally or using sattelite data; Kendryte K210; RISC-V 64b; nncase; 8-bit Quant; Multi-Hazard Sensors OV5647 Telephoto; Davis 7852 Rain; YG1006 IR Flame; ADXL355 Low-Noise; Mesh & Connectivity UART / SPI; 12C Bus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

Edge AI & Hardware

Maixduino Ai+IOT
K210 ESP32

Stores Data in
Memory Card

Checks
different
sports live for
disaster

SMS/Call
Warning on all
registered
device

Predictive Hub & Gateway

Alerting & Civil Defense Direct SMS

Mobile app to
flash the
firmware

30%
10%

15%

20%

25%

12V 15–20Ah LiFePO4 packs, monocrystalline solar, MPPT chargers

433 MHz LoRa transceivers, antennas, GSM modules

Kendryte K210 + ESP32
modules, M12 telephoto lenses

Power Systems:

Vision & Compute Nodes:

Telemetry & Repeaters:

Modular Daughterboards:
Rain gauges, flame sensors, seismic accelerometers

Central Hub & Enclosures:
Raspberry Pi field gateway, IP65 weatherproof housings

# FEASIBILITY AND VIABILITY

Financials

Silicon Edge Inference: Dedicated KPU runs quantized MobileNet CNNs at 0.3W, eliminating cloud dependency.

Elevated Long-Range Optics: 20–30m elevated mount with narrow-FOV lenses survives 15–25m flood surges

Sub-GHz LoRa Mesh: 433 MHz radio penetrates mountain valleys and foliage via 14-byte compact binary packets.

Hardware Power-Gating: ESP32 timer cuts K210 idle draw to 0 mA, slashing consumption to ~150–180 mAh/day.

Feasibility

Audit-Ready Escalation: Transparent, rule-based logic complies with government disaster-management standards.

Zero-Calibration Adaptability: 30-day rolling baselines auto-adjust to any river geometry.

Modular Multi-Hazard Design: Universal baseboard supports floods, forest fires, and landslides via swappable sensor boards.

Actionable Lead Time: Upstream kinematic modeling provides hours of warning vs. minutes from water-level detectors.

Viability

Extended Dark/
Monsoon Periods

10–14 day LiFePO4 battery autonomy + adaptive wake-interval throttling (10 to 60 mins).

Mesh Relay vs. Sleep
Conflicts

Split power domains: ESP32/LoRa stays listening (Domain A) while K210/camera sleeps (Domain B).

Mountain Line-of-Sight Blockage

Multi-hop mesh networking with dedicated solar-powered repeaters placed along high ridgelines.

Mud, Algae & Lens
Obstruction

Downward-angled rain hoods + firmware-level contrast checks that auto-flag "sensor obstructed".

Challenges and Mitigation

### PrakritiNetX

## IMPACT

# IMPACT & BENEFITS

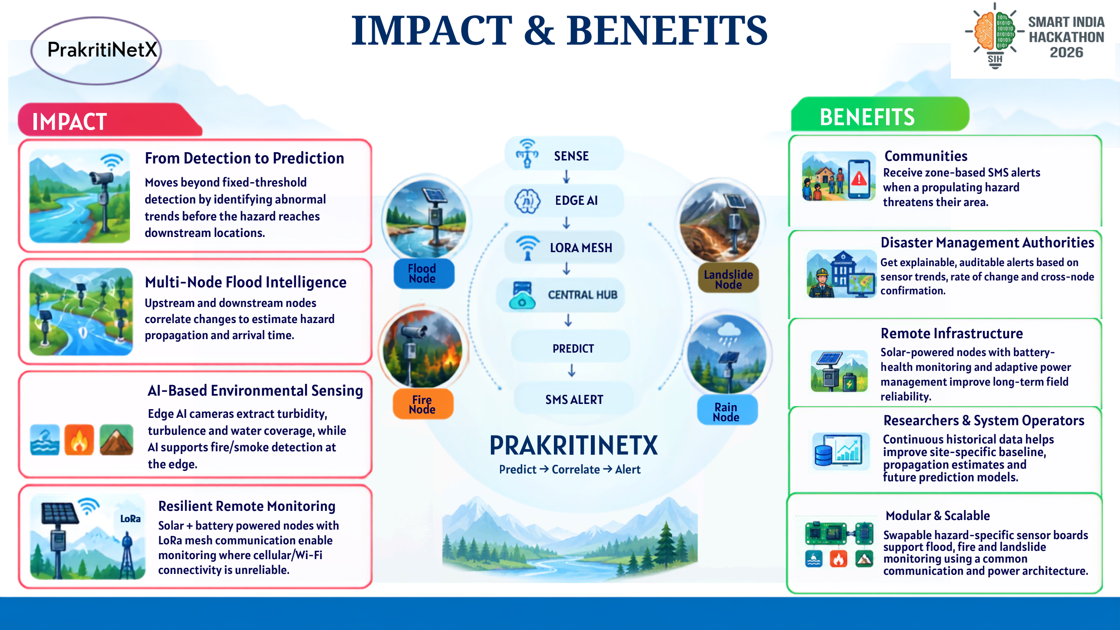
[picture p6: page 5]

From Detection to Prediction
Moves beyond fixed-threshold detection by identifying abnormal trends before the hazard reaches downstream locations.

Multi-Node Flood Intelligence
Upstream and downstream nodes correlate changes to estimate hazard propagation and arrivaltime.

AI-Based Environmental Sensing
Edge AI cameras extractturbidity, turbulence and water coverage, while AI supports fire/smoke detection at
the edge.

Resilient Remote Monitoring
Solar + battery powered nodes with LoRa mesh communication enable monitoring where cellular/Wi-Fi connectivity is unreliable.

Flood
Node

Fire
Node

LORA MESH

Communities
Receive zone-based SMS alerts
when a propulating hazard
threatens their area.

Disaster Management Authorities
Get explainable, auditable alerts based on sensortrends,rate of change and cross-node confirmation.

Remote Infrastructure
Solar-powered nodes with battery-health monitoring and adaptive power managementimprove long-term field reliability.
Researchers & System Operators
Continuous historical data helps improve site-specific baseline, propagation estimates and
future prediction models.

Modular & Scalable
Swapable hazard-specific sensor boards supportflood, fire and landslide monitoring using a common
communication and power architecture.

SENSE

EDGE AI

PREDICT

SMS ALERT
Rain
Node

## BENEFITS

# PRAKRITINETX

Predict → Correlate → Alert

LoRa

Landslide
Node

### PrakritiNetX

# RESEARCH AND REFERENCES

# Research Papers

Flood/Disaster Early Warning Systems
Remote Early Warning System for Mountain Floods with Robust ZigBee Wireless Networks — Mobile Networks and Applications, Springer, 2023
Early Warning of Impending Flash Flood Based on AIoT — EURASIP Journal on Wireless Communications and Networking, 2022 (directly relevant: uses LoRa + SIM900 cellular backup for mountain slope monitoring, near-identical to your dual LoRa/SIM architecture)
LoRa-based IoT Sensor Node for Real-time Flood Early Warning System — IOP Conf. Series: Earth and Environmental Science, 2022
Flood Early Warning System by Twitter Using LoRa — river-level ultrasonic sensing + Raspberry Pi processing + mesh topology, ResearchGate
Development of a Smart Sensing Unit for LoRaWAN-based IoT Flood Monitoring and Warning System in Catchment Areas — ScienceDirect, 2023

Edge AI / On-device Vision
We designed and implemented WaterNet, a lightweight custom CNN architecture (approximately 90K parameters) for on-device river water segmentation, deployed directly on the K210's hardware KPU via the nncase v0.2 compilation pipeline. This is an original contribution of our project rather than an adaptation of prior published work — full architecture, training pipeline, and export process are documented in our repository (Software/ML_Model/) and technical reference document.

Government Applications
NDMA Common Alerting Protocol (CAP) and SACHET platform — National Disaster Management Authority, Government of India
Central Water Commission (CWC) flood forecasting operational standards — Government of India

### PrakritiNetX

### Github Link

https://github.com/Rohan-Gupta99/PrakritiNetX

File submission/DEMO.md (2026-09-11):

# Demo Video

## PrakritiNetX – AI-Accelerated Environmental Early Warning Network

**PS ID:** SIH2026-26178  
**Theme:** Disaster Management  
**Category:** Hardware

---

## Demo

🎬 [Watch Demo Video on Google Drive](https://drive.google.com/drive/folders/1vZj6SV4yedn8AnQawvWaI9Jvdcg6W1Xi?usp=sharing)

> Ensure the link is set to "Anyone with the link can view" before submission.

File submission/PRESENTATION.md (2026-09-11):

# Final Presentation

## PrakritiNetX – AI-Accelerated Environmental Early Warning Network

**PS ID:** SIH2026-26178  
**Theme:** Disaster Management  
**Category:** Hardware

---

## Presentation

📎 [View Presentation on Google Drive](https://drive.google.com/drive/folders/1Dz8FVQ1AMcFOIODErVW3VQj4AWxJVNVZ?usp=sharing)

> Ensure the link is set to "Anyone with the link can view" before submission.

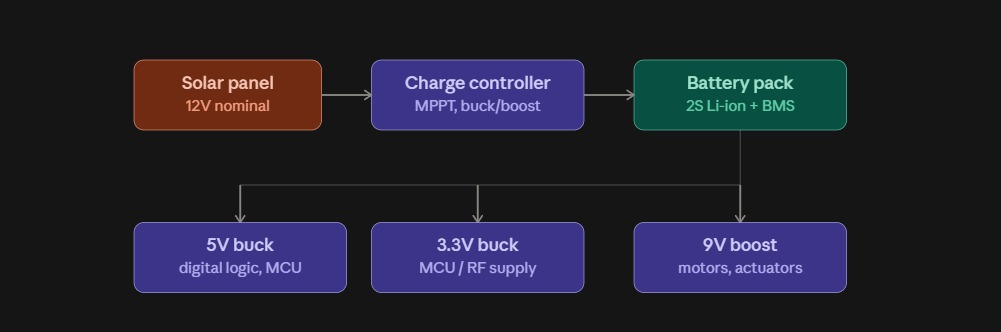
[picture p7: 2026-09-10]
assets/screenshots/power_architecture.png.jpeg

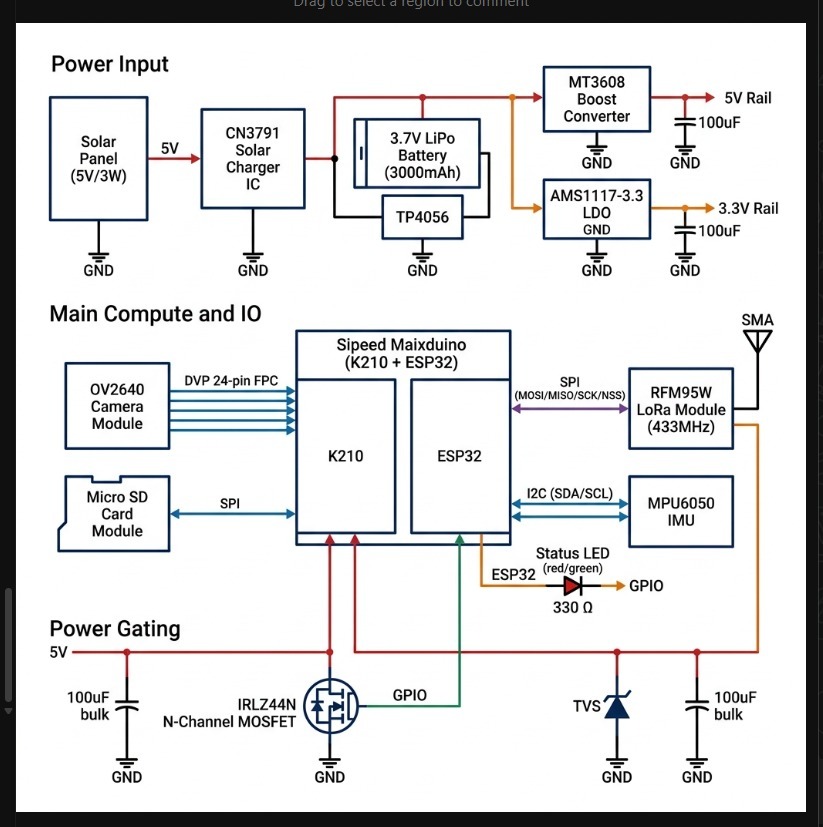
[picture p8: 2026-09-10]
assets/screenshots/hardware_block_diagram.png.jpeg

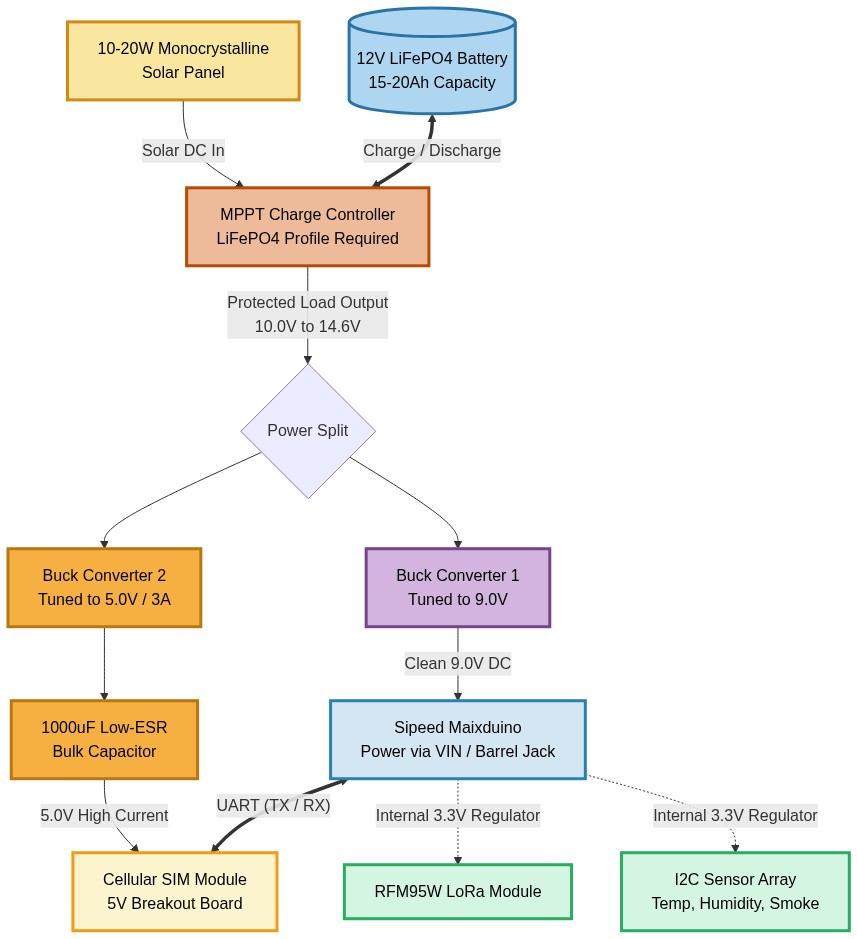
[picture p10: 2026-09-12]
Hardware/AI BOARD MAIN HOUSE/power_system_diagram_.png

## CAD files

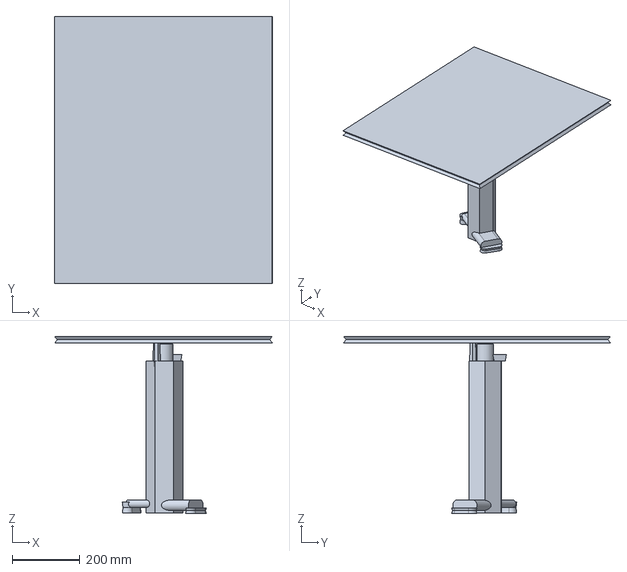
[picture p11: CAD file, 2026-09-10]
Hardware/PRODUCT_DESIGN/3D_MODEL_NODE_POLE/SIH_PV_Panel_towerF.FCStd
645.8 x 791.1 x 524.9 mm

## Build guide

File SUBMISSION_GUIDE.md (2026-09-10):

# SIH 2026 Submission Guide

Use this checklist before sharing your GitHub repository link.

---

## Required Repository Content

- [x] Actual source code is present.
- [x] `README.md` explains the project clearly.
- [x] PS ID and PS title are included.
- [x] Problem statement and proposed solution are explained.
- [x] Key features are listed.
- [x] Technology stack is listed.
- [x] Setup and run instructions work.
- [ ] Team members and roles are mentioned.
- [ ] Important screenshots or hardware/prototype photos are included.
- [ ] Final PPT/presentation is placed in `submission/` whenever practical.
- [ ] If the PPT is too large for GitHub, an accessible Google Drive/OneDrive viewer link is added to `submission/PRESENTATION.md`.
- [ ] Demo video link is added to `submission/DEMO.md` if available. *(Optional)*
- [ ] Repository is accessible to reviewers.

---

## Recommended Structure

```
PrakritiNetX/
├── README.md
├── SUBMISSION_GUIDE.md
├── submission/
│   ├── PRESENTATION.md
│   └── DEMO.md
├── Software/
│   ├── ML_Model/
│   └── Mobile Firmware Flasher Application/
├── Hardware/
├── Docs/
├── docs/
│   └── architecture.md
├── assets/
│   └── screenshots/
├── LICENSE
├── .gitignore
└── requirements.txt
```

---

## Presentation

Upload the final PPT/PPTX to the `submission/` folder when the file size is suitable for GitHub. Use a clear filename such as:

```
TeamName_SIH2026_Presentation.pptx
```

If the PPT is too large, use Google Drive or OneDrive and put the shareable viewer link in `submission/PRESENTATION.md`.

---

## Demo Video

The demo video is optional. If you have one, add its YouTube/Google Drive link to `submission/DEMO.md` and make sure it is accessible without requesting permission.

---

## Screenshots / Hardware Photos

Put important screenshots and prototype photos in `assets/screenshots/`. Include the most useful screens/results rather than random development screenshots.

---

## Do Not Upload

- ❌ Passwords
- ❌ API keys
- ❌ Access tokens
- ❌ `.env` files containing secrets
- ❌ Private credentials
- ❌ Other confidential information

---

## README Should Answer

- ✅ What problem are you solving?
- ✅ What is your proposed solution?
- ✅ How does it work?
- ✅ Which technologies did you use?
- ✅ How can a reviewer run it?
- ✅ What does the final output look like?
- ✅ What are the important features and expected impact?

---

## Before Submission

Open your repository in a **private/incognito browser window** or while logged out and verify that the reviewer can access the code, PPT, screenshots, documentation, and any submitted links that are supposed to be public.

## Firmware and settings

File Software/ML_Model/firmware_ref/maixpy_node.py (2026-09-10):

"""
PrakritiNetX vision node - MaixPy firmware for the Kendryte K210.

  ####################################################################
  #  NOT YET RUN ON HARDWARE. Written against the MaixPy API but      #
  #  untested on a real board - expect small fixes on first flash.    #
  #  Every spot needing on-device verification is marked  # VERIFY    #
  ####################################################################

WHAT THIS DOES, ONCE PER WAKE CYCLE (every ~15 minutes)
-------------------------------------------------------
  1. wake, start the camera
  2. take a BURST of 5 frames about half a second apart
  3. run waternet.kmodel on each -> a 32x32 map of "is this water?"
  4. turn those maps into physical numbers:
        water level, coverage, turbidity, turbulence, debris, lens health
  5. send one compact binary packet to the ESP32 over UART
  6. power down

It deliberately makes NO flood decision. It measures; the ESP32 compares
against this river's learned normal, and the hub correlates across nodes.

FLASHING
--------
  waternet.kmodel  ->  flash offset 0x300000
  this file        ->  /sd/main.py  (or boot.py in internal flash)
"""

import sensor, image, time, gc
from machine import UART
from fpioa_manager import fm
import KPU as kpu

# ---------------------------------------------------------------------------
# Site configuration - SET THESE AT INSTALLATION, per node
# ---------------------------------------------------------------------------

NODE_ID = 1

MODEL_ADDR = 0x300000       # where waternet.kmodel sits in SPI flash
IN_SIZE    = 128            # model input  (128 x 128)
OUT_SIZE   = 32             # model output (32 x 32 grid)

# The river channel inside the frame, in output-grid cells (col0, row0, col1, row1).
# The camera never moves, so this is fixed once with a tape measure and a photo.
# Everything outside it (sky, road, trees) is ignored entirely.
ROI = (4, 10, 28, 32)

# Calibration: two points on a gauge board / bridge pier whose real heights are
# known. Converts a grid row into metres.            # VERIFY on the real site
CAL_ROW_A,  CAL_HEIGHT_A = 28, 0.00     # low mark: grid row 28 == 0.00 m
CAL_ROW_B,  CAL_HEIGHT_B = 12, 3.50     # high mark: grid row 12 == 3.50 m

# A patch of something in frame whose true colour NEVER changes - concrete, a
# boulder, a painted board. Used to cancel out sunlight so that turbidity means
# "how muddy" rather than "what time of day is it".  (col0,row0,col1,row1)
REF_PATCH = (2, 2, 8, 7)

BURST_N     = 5             # frames per wake cycle
BURST_MS    = 500           # gap between them
WATER_THRESH = 0.5          # confidence above which a cell counts as water


# ---------------------------------------------------------------------------
# Setup
# ---------------------------------------------------------------------------

def init_camera():
    sensor.reset()
    sensor.set_pixformat(sensor.RGB565)
    sensor.set_framesize(sensor.QVGA)          # 320x240
    sensor.set_vflip(False)                    # VERIFY against real mounting
    sensor.set_hmirror(False)
    sensor.skip_frames(time=800)               # let exposure settle
    sensor.set_auto_gain(False)                # VERIFY: locking gain/whitebalance
    sensor.set_auto_whitebal(False)            #   is ESSENTIAL - see note below
    return True

# WHY GAIN AND WHITE-BALANCE MUST BE LOCKED
# -----------------------------------------
# With auto white-balance on, the camera "corrects" the colour of muddy water
# back toward grey - it actively erases the exact signal we are trying to
# measure. Auto-gain does the same to brightness. Lock both, so that a colour
# change between two frames means the RIVER changed, not the camera.


def init_uart():
    fm.register(10, fm.fpioa.UART1_TX, force=True)   # VERIFY pins on your board
    fm.register(11, fm.fpioa.UART1_RX, force=True)
    return UART(UART.UART1, 115200, timeout=1000, read_buf_len=256)


# ---------------------------------------------------------------------------
# Inference
# ---------------------------------------------------------------------------

def run_model(task):
    """Capture one frame and return (32x32 water confidences 0..1, the frame)."""
    img = sensor.snapshot()
    small = img.resize(IN_SIZE, IN_SIZE)
    small.pix_to_ai()
    fmap = kpu.forward(task, small)
    return fmap[:], img          # fmap[:] is a flat list of OUT_SIZE*OUT_SIZE floats


def cell(grid, col, row):
    return grid[row * OUT_SIZE + col]


# ---------------------------------------------------------------------------
# Turning the water map into physical numbers
# ---------------------------------------------------------------------------

def water_coverage(grid):
    """Fraction of the river channel currently covered by water (0..1)."""
    c0, r0, c1, r1 = ROI
    wet = total = 0
    for r in range(r0, r1):
        for c in range(c0, c1):
            total += 1
            if cell(grid, c, r) > WATER_THRESH:
                wet += 1
    return wet / float(total or 1)


def water_line_row(grid):
    """
    Find the top edge of the water, to better precision than the 32x32 grid.

    For each column we walk DOWN from the top of the channel until confidence
    crosses 0.5. Because the model outputs a smooth confidence rather than a
    hard yes/no, we can interpolate between the cell above and the cell below
    to locate the edge to roughly a quarter of a cell.

    We then take the MEDIAN across columns, not the mean: a single log or a
    glint of sun can throw one column badly, and the median ignores it.
    """
    c0, r0, c1, r1 = ROI
    rows = []
    for c in range(c0, c1):
        prev = cell(grid, c, r0)
        for r in range(r0 + 1, r1):
            cur = cell(grid, c, r)
            if prev <= WATER_THRESH < cur:              # dry above, wet below
                span = cur - prev
                frac = (WATER_THRESH - prev) / span if span > 1e-6 else 0.5
                rows.append((r - 1) + frac)
                break
            prev = cur
    if not rows:
        return None
    rows.sort()
    return rows[len(rows) // 2]


def row_to_metres(row):
    """Convert a grid row into a real water level using the two calibration marks."""
    if row is None:
        return None
    dr = CAL_ROW_B - CAL_ROW_A
    if dr == 0:
        return None
    t = (row - CAL_ROW_A) / float(dr)
    return CAL_HEIGHT_A + t * (CAL_HEIGHT_B - CAL_HEIGHT_A)


def turbidity(img, grid):
    """
    How muddy the water looks, normalised against a fixed reference patch.

    Raw colour is useless on its own: muddy water at noon and clear water at
    dusk read almost identically. Dividing the water's colour by the colour of
    something whose true colour cannot change cancels the sunlight out.

    Returns 0..255, where higher means browner/more sediment-laden.
    """
    sx = img.width() // OUT_SIZE
    sy = img.height() // OUT_SIZE

    def patch_rgb(c0, r0, c1, r1, water_only):
        rs = gs = bs = n = 0
        for r in range(r0, r1):
            for c in range(c0, c1):
                if water_only and cell(grid, c, r) <= WATER_THRESH:
                    continue
                px = img.get_pixel(c * sx + sx // 2, r * sy + sy // 2)
                rs += px[0]; gs += px[1]; bs += px[2]; n += 1
        if n == 0:
            return None
        return (rs / n, gs / n, bs / n)

    w = patch_rgb(ROI[0], ROI[1], ROI[2], ROI[3], True)
    ref = patch_rgb(REF_PATCH[0], REF_PATCH[1], REF_PATCH[2], REF_PATCH[3], False)
    if w is None or ref is None:
        return None

    # illumination-cancelled colour
    nr = w[0] / max(ref[0], 1.0)
    nb = w[2] / max(ref[2], 1.0)
    # sediment shifts water toward red/brown and away from blue
    ratio = nr / max(nb, 0.05)
    return max(0, min(255, int((ratio - 0.6) * 160)))


def turbulence(grids):
    """
    Surface agitation: how much each water cell flickered across the burst.

    A calm pool barely changes between frames. Fast, broken, white water
    changes a lot. This is why we take a burst - it is not computable from a
    single frame.
    """
    if len(grids) < 2:
        return None
    c0, r0, c1, r1 = ROI
    total = 0.0
    n = 0
    for r in range(r0, r1):
        for c in range(c0, c1):
            vals = [cell(g, c, r) for g in grids]
            m = sum(vals) / len(vals)
            if m <= WATER_THRESH:
                continue
            var = sum((v - m) ** 2 for v in vals) / len(vals)
            total += var
            n += 1
    if n == 0:
        return 0
    return max(0, min(255, int((total / n) * 2000)))


def debris_count(grid):
    """
    Count non-water patches that are SURROUNDED by water.

    Floating debris is, by definition, something that is not water sitting in
    the middle of water. Since we already have the water map this is free, and
    it needs no debris training data at all.

    Rocks near the bank are excluded because they touch the edge of the water
    region rather than being enclosed by it.
    """
    c0, r0, c1, r1 = ROI
    found = 0
    for r in range(r0 + 1, r1 - 1):
        for c in range(c0 + 1, c1 - 1):
            if cell(grid, c, r) > WATER_THRESH:
                continue
            neigh = (cell(grid, c - 1, r), cell(grid, c + 1, r),
                     cell(grid, c, r - 1), cell(grid, c, r + 1))
            if sum(1 for v in neigh if v > WATER_THRESH) >= 3:
                found += 1
    return min(15, found)


def lens_ok(img):
    """
    Is the lens clear?

    A muddy, fogged, iced or spider-webbed lens makes every reading above
    meaningless - and does so silently, which is the dangerous part. Sharp
    images have strong local contrast; an obstructed one is smooth mush.

    Turning a silent failure into a reported one is more valuable than trying
    to prevent it.
    """
    stat = img.get_statistics()
    return stat.stdev() > 8          # VERIFY threshold against real site images


# ---------------------------------------------------------------------------
# Packet: what we hand to the ESP32
# ---------------------------------------------------------------------------

def build_packet(level_cm, coverage, turb, turbu, debris, ok, night):
    """
    18 bytes, fixed layout. Compact because LoRa airtime costs power.

      0     node id
      1-2   water level, cm above datum
      3     coverage percent
      4     turbidity 0-255
      5     turbulence 0-255
      6     debris count (low nibble) + flags (high nibble)
      7     status flags
      8-16  reserved for ESP32 to fill in (rates of change, battery, time)
      17    checksum
    """
    p = bytearray(18)
    p[0] = NODE_ID & 0xFF
    lv = 0xFFFF if level_cm is None else max(0, min(65534, int(level_cm)))
    p[1] = (lv >> 8) & 0xFF
    p[2] = lv & 0xFF
    p[3] = int(coverage * 100) & 0xFF
    p[4] = 0xFF if turb is None else turb & 0xFF        # 0xFF = not measurable
    p[5] = 0xFF if turbu is None else turbu & 0xFF
    p[6] = debris & 0x0F
    p[7] = (0x01 if ok else 0) | (0x02 if night else 0)
    c = 0
    for b in p[:17]:
        c ^= b
    p[17] = c
    return p


# ---------------------------------------------------------------------------
# Main cycle
# ---------------------------------------------------------------------------

def main():
    init_camera()
    uart = init_uart()

    task = kpu.load(MODEL_ADDR)
    try:
        grids = []
        last_img = None
        for i in range(BURST_N):
            g, img = run_model(task)
            grids.append(g)
            last_img = img
            if i < BURST_N - 1:
                time.sleep_ms(BURST_MS)

        # Use the median frame for still measurements so one glitched frame
        # (a bird, a splash, an exposure hiccup) cannot dominate the reading.
        mid = grids[len(grids) // 2]

        ok = lens_ok(last_img)
        night = last_img.get_statistics().mean() < 40    # VERIFY threshold

        cov = water_coverage(mid)
        row = water_line_row(mid)
        lvl_m = row_to_metres(row)
        lvl_cm = None if lvl_m is None else lvl_m * 100.0

        # Turbidity comes from colour, and IR night frames have none.
        turb = turbidity(last_img, mid) if (ok and not night) else None
        turbu = turbulence(grids)
        deb = debris_count(mid)

        pkt = build_packet(lvl_cm, cov, turb, turbu, deb, ok, night)
        uart.write(pkt)

        print("level={} cm  coverage={:.0f}%  turbidity={}  turbulence={}  debris={}  lens_ok={}".format(
            "?" if lvl_cm is None else int(lvl_cm), cov * 100, turb, turbu, deb, ok))

    finally:
        # Always free the model, even on error - the K210 has little RAM and a
        # leak here bricks the next wake cycle.
        kpu.deinit(task)
        gc.collect()


if __name__ == "__main__":
    main()

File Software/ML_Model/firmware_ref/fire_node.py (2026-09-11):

"""
PrakritiNetX Fire Node - MaixPy firmware for the Kendryte K210.

WHAT THIS DOES, ONCE PER WAKE CYCLE (every ~5 minutes)
-------------------------------------------------------
  1. wake, start the camera
  2. take a BURST of 3 frames to check for spreading
  3. run firenet.kmodel on each -> a 32x32 map of "is this fire/smoke?"
  4. turn those maps into physical numbers:
        fire presence, fire size (coverage), fire growth (spreading rate), lens health
  5. send one compact binary packet to the ESP32 over UART
  6. power down

FLASHING
--------
  firenet.kmodel   ->  flash offset 0x300000
  this file        ->  /sd/main.py  (or boot.py in internal flash)
"""

import sensor, image, time, gc
from machine import UART
from fpioa_manager import fm
import KPU as kpu

# ---------------------------------------------------------------------------
# Site configuration - SET THESE AT INSTALLATION, per node
# ---------------------------------------------------------------------------

NODE_ID = 2

MODEL_ADDR = 0x300000       # where firenet.kmodel sits in SPI flash
IN_SIZE    = 128            # model input  (128 x 128)
OUT_SIZE   = 32             # model output (32 x 32 grid)

# The region of interest. For a forest camera looking at the horizon,
# the top 1/4 is likely just open sky. We ignore it to reduce false positives
# from the sun. (col0, row0, col1, row1)
ROI = (0, 8, 32, 32)

BURST_N      = 3            # frames per wake cycle (fewer than water to save power)
BURST_MS     = 1000         # 1 second gap between them to see smoke drift
FIRE_THRESH  = 0.65         # high confidence required to count a cell as burning


# ---------------------------------------------------------------------------
# Setup
# ---------------------------------------------------------------------------

def init_camera():
    sensor.reset()
    sensor.set_pixformat(sensor.RGB565)
    sensor.set_framesize(sensor.QVGA)          # 320x240
    sensor.set_vflip(False)                    # VERIFY against real mounting
    sensor.set_hmirror(False)
    sensor.skip_frames(time=800)               # let exposure settle
    # UNLIKE the water node, we DO NOT lock white balance here.
    # Fire and smoke can happen at any time of day, and we want the camera
    # to adapt so the image isn't pitch black at dusk or blown out at noon.
    return True


def init_uart():
    fm.register(10, fm.fpioa.UART1_TX, force=True)   # VERIFY pins on your board
    fm.register(11, fm.fpioa.UART1_RX, force=True)
    return UART(UART.UART1, 115200, timeout=1000, read_buf_len=256)


# ---------------------------------------------------------------------------
# Inference
# ---------------------------------------------------------------------------

def run_model(task):
    img = sensor.snapshot()
    small = img.resize(IN_SIZE, IN_SIZE)
    small.pix_to_ai()
    fmap = kpu.forward(task, small)
    return fmap[:], img


def cell(grid, col, row):
    return grid[row * OUT_SIZE + col]


# ---------------------------------------------------------------------------
# Turning the fire map into physical numbers
# ---------------------------------------------------------------------------

def fire_size_cells(grid):
    """How many grid cells are currently burning/smoking."""
    c0, r0, c1, r1 = ROI
    burning = 0
    for r in range(r0, r1):
        for c in range(c0, c1):
            if cell(grid, c, r) > FIRE_THRESH:
                burning += 1
    return burning


def fire_growth(grids):
    """
    Are there more burning cells in the last frame than the first frame?
    This helps identify spreading fire vs a static false positive (like a bright rock).
    Returns growth in cells (can be negative if smoke is dissipating).
    """
    if len(grids) < 2:
        return 0
    start_size = fire_size_cells(grids[0])
    end_size = fire_size_cells(grids[-1])
    return end_size - start_size


def lens_ok(img):
    """Is the lens clear? (Same as water node)"""
    stat = img.get_statistics()
    return stat.stdev() > 8


# ---------------------------------------------------------------------------
# Packet: what we hand to the ESP32
# ---------------------------------------------------------------------------

def build_packet(is_fire, size_cells, growth, ok, night):
    """
    18 bytes, fixed layout for LoRa.
    
      0     node id
      1     alert flag (1 = FIRE DETECTED)
      2-3   size of fire (number of grid cells)
      4     growth (0-255, where 128 is 0 growth, >128 is growing)
      5     status flags
      6-16  reserved for ESP32
      17    checksum
    """
    p = bytearray(18)
    p[0] = NODE_ID & 0xFF
    p[1] = 1 if is_fire else 0
    
    s = max(0, min(65535, size_cells))
    p[2] = (s >> 8) & 0xFF
    p[3] = s & 0xFF
    
    g_mapped = max(0, min(255, 128 + growth)) # shift so 128 is neutral
    p[4] = g_mapped & 0xFF
    
    p[5] = (0x01 if ok else 0) | (0x02 if night else 0)
    
    c = 0
    for b in p[:17]:
        c ^= b
    p[17] = c
    return p


# ---------------------------------------------------------------------------
# Main cycle
# ---------------------------------------------------------------------------

def main():
    init_camera()
    uart = init_uart()

    task = kpu.load(MODEL_ADDR)
    try:
        grids = []
        last_img = None
        for i in range(BURST_N):
            g, img = run_model(task)
            grids.append(g)
            last_img = img
            if i < BURST_N - 1:
                time.sleep_ms(BURST_MS)

        mid_grid = grids[len(grids) // 2]
        
        ok = lens_ok(last_img)
        night = last_img.get_statistics().mean() < 30

        size = fire_size_cells(mid_grid)
        
        # We need at least 2 connected cells to consider it a real fire to prevent 1-pixel false alarms
        is_fire = size >= 2
        growth = fire_growth(grids)

        pkt = build_packet(is_fire, size, growth, ok, night)
        uart.write(pkt)

        print("FIRE ALERT={}  size={} cells  growth={}  lens_ok={}".format(
            "YES!" if is_fire else "No", size, growth, ok))

    finally:
        kpu.deinit(task)
        gc.collect()


if __name__ == "__main__":
    main()

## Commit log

2026-09-10 feat(enterprise): upgrade FieldFlash to production architecture with multi-constellation GNSS, live node telemetry, JEDEC SPI flash probing, and enterprise documentation
2026-09-10 schematic added
    [Sensor_board.kicad_pcb, Sensor_board.kicad_sch]
2026-09-10 schematic updated
    [Lorawan.kicad_sch, camere_sd.kicad_sch, temp_humidity.kicad_sch]
2026-09-11 final submission — add presentation PDF and technical approach diagram
2026-09-12 Power_system_Block updated
